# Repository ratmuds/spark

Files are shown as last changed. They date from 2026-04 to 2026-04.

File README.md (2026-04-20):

# spark

an electronic multitool in the shape of a card

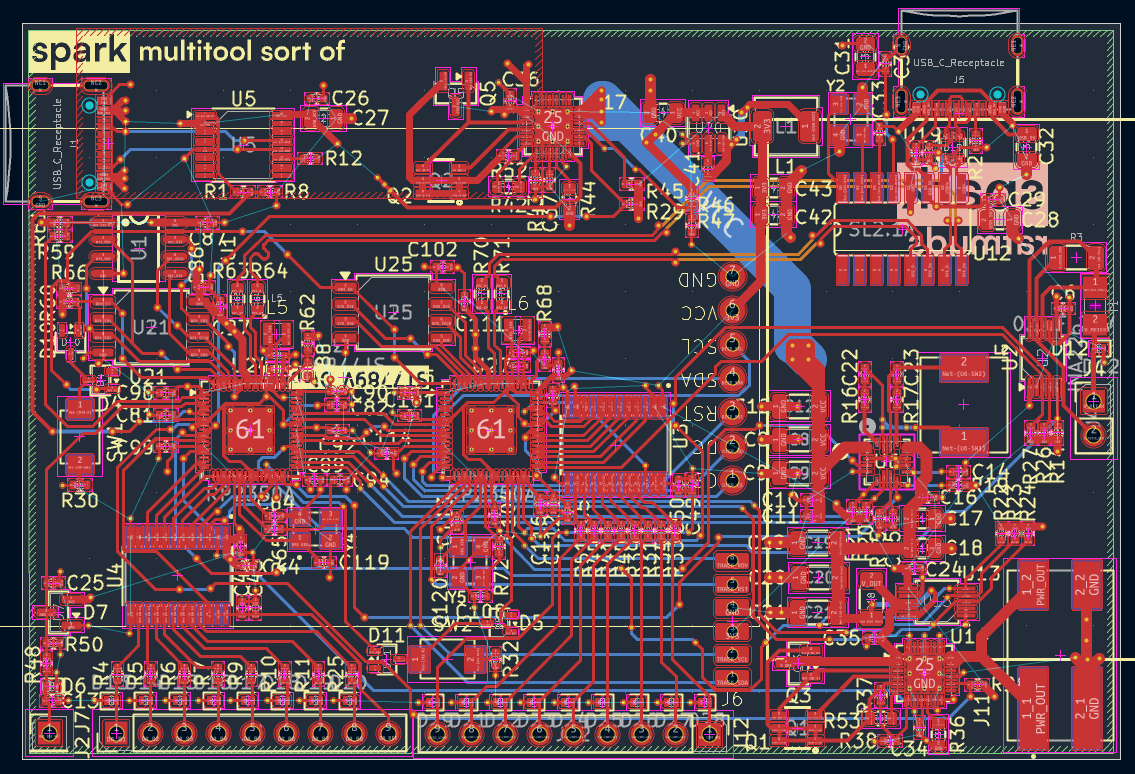
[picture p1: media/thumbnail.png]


# Features

- dual RP2350As (one logic analyzer & power, other LVGL & inputs)
- 8 channel logic analyzer
- very slow ADC
- GPIO
- up to 20V 3A power output

# Files

- `/case`: The CAD for the case for the PCB. Includes a Fusion archive file, step, and stl file
- `/firmware`: Includes the firmware for both MCUs for this project. `/main` is in Rust and handles the logic analyzer, and `/secondary` is the input and LVGL C files
- `/PCB`: The PCB files for this project. The producton/gerber files are in `/production`
- `/media`: The screenshots/renders

## More Screenshots

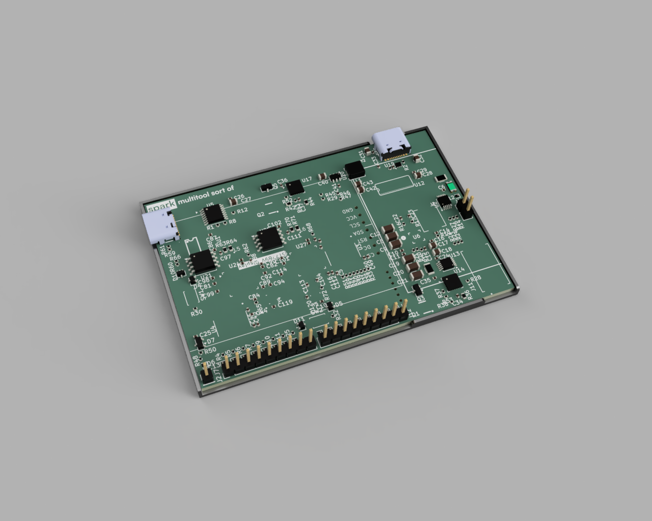
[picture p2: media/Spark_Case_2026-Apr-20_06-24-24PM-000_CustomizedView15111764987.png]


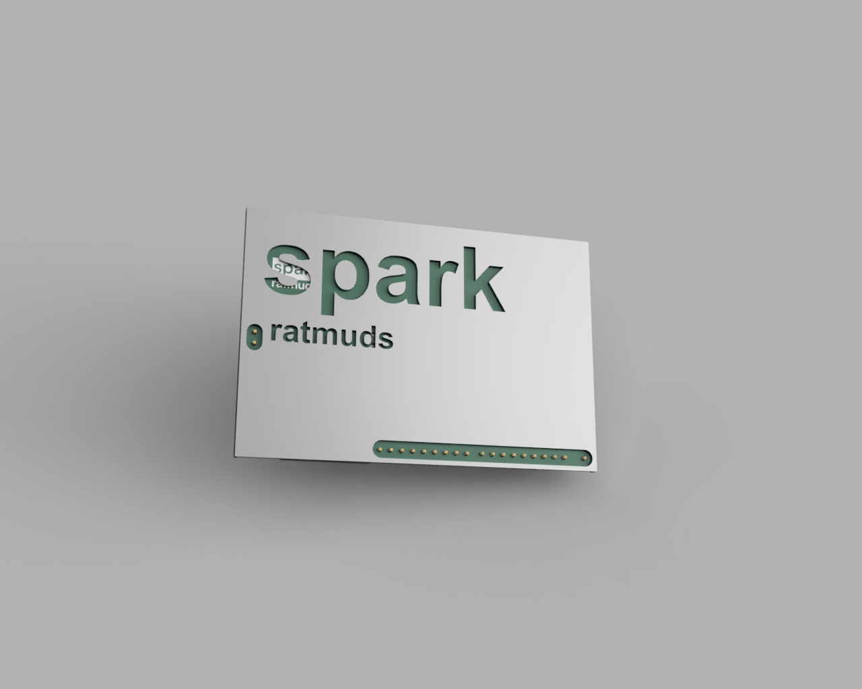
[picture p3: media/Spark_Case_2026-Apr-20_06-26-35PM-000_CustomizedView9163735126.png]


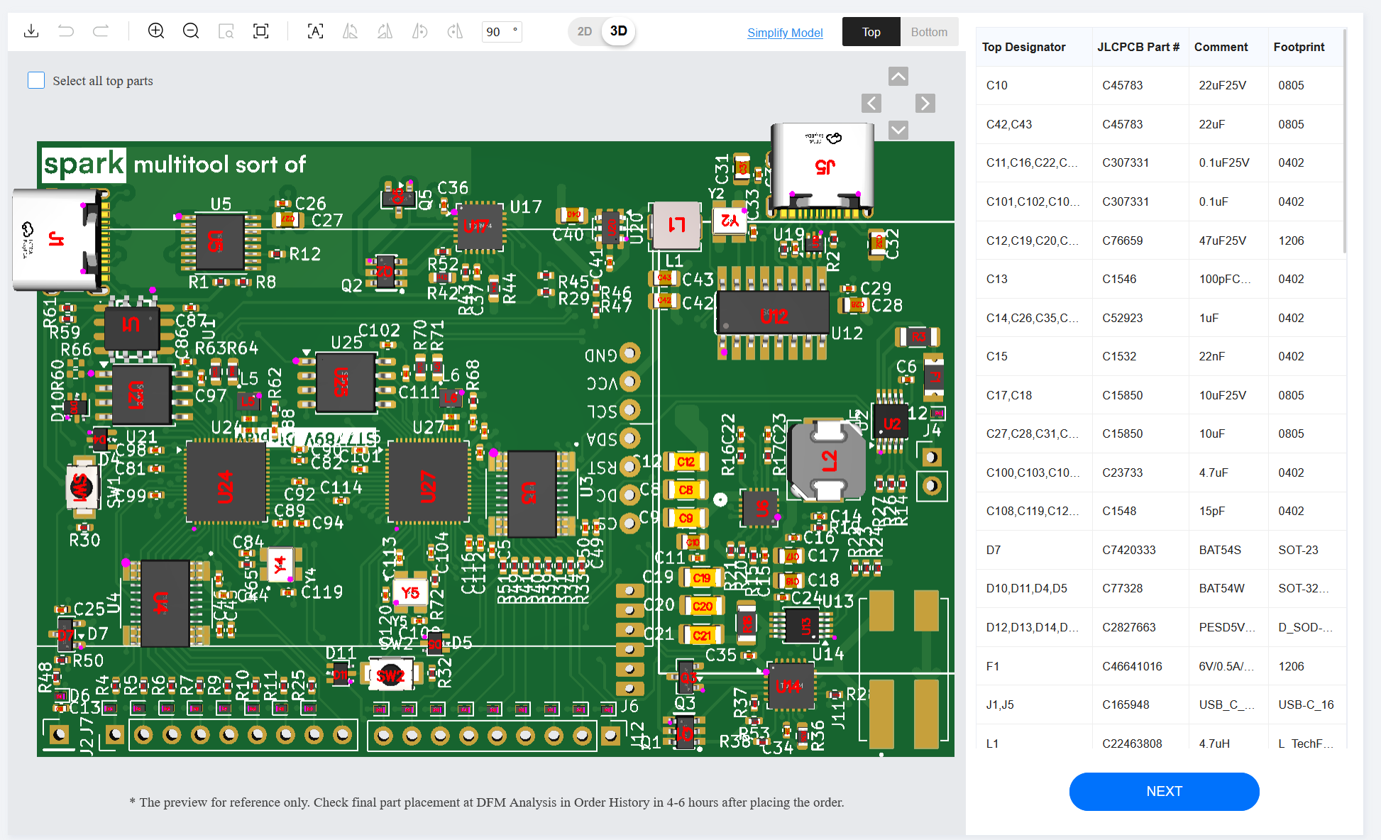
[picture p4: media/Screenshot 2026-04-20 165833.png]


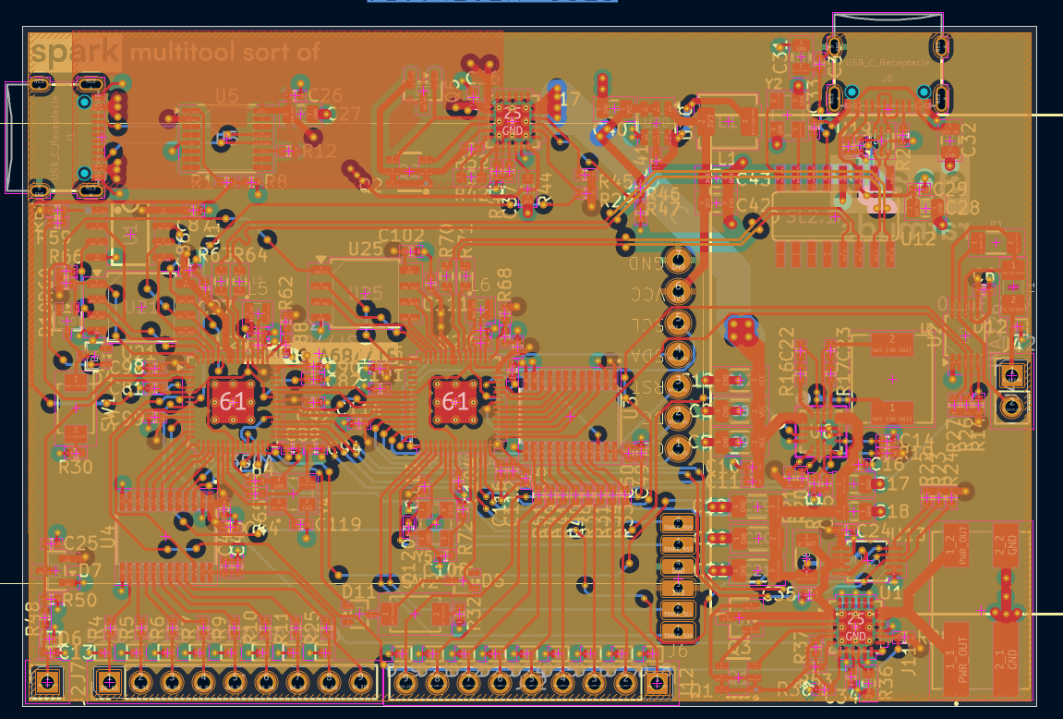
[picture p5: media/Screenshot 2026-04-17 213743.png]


## Bill of Materials

You can also view the BOM in `BOM.csv`

| Name | Description | Link |
| --- | --- | --- |
| RP2350A | Dual-core ARM Cortex-M33 / RISC-V microcontroller 30 GPIO QFN-60 (x2) | https://jlcpcb.com/partdetail/RaspberryPi-RP2350A/C42411118 |
| W25Q128JVSIQ | 128Mbit SPI NOR Flash SOIC-8 (x2) | https://jlcpcb.com/partdetail/WinbondElec-W25Q128JVSIQ/C97521 |
| APS6404L-SQN-SN | 64Mbit QSPI PSRAM SOP-8 (x1) | https://jlcpcb.com/partdetail/APMemory-APS6404L_SQNSN/C5360304 |
| INA226AIDGSR | 36V 16-bit I2C Power Monitor TSSOP-10 (x2) | https://jlcpcb.com/partdetail/TexasInstruments-INA226AIDGSR/C49851 |
| SN74LVC8T245PWR | 8-bit dual-supply level shifter TSSOP-24 (x2) | https://jlcpcb.com/partdetail/TexasInstruments-SN74LVC8T245PWR/C27643 |
| IP2721 | USB PD sink controller TSSOP-16 (x1) | https://jlcpcb.com/partdetail/INJOINIC-IP2721/C603176 |
| MP8859GQ-0000-Z | Programmable synchronous buck converter QFN-16 (x1) | https://jlcpcb.com/partdetail/MPS-MP8859GQ_0000Z/C5439043 |
| SL2.1A | 4-port USB 2.0 hub controller SO-16 (x1) | https://jlcpcb.com/partdetail/Corechips-SL21A/C192893 |
| TPS26630RGER | 45V 5.5A eFuse with reverse polarity VQFN-24 (x2) | https://jlcpcb.com/partdetail/TexasInstruments-TPS26630RGER/C1850276 |
| USBLC6-2P6 | USB ESD protection SOT-666 (x1) | https://jlcpcb.com/partdetail/STMicroelectronics-USBLC62P6/C15999 |
| AP63203WU-7 | 3.3V 2A synchronous buck converter TSOT-23-6 (x1) | https://jlcpcb.com/partdetail/DiodesIncorporated-AP63203WU7/C780769 |
| ABM8-272-T3 | 12MHz crystal oscillator RPi recommended SMD (x3) | https://jlcpcb.com/partdetail/AbraconLlc-ABM8_272T3/C20625731 |
| AOTA-B201610S3R3-101-T | 3.3uH polarised inductor for RP2350 DVDD SMPS 2016 (x2) | https://jlcpcb.com/partdetail/AbraconLlc-AOTA_B201610S3R3_101T/C42411119 |
| SRP4020TA-4R7M | 4.7uH 2.6A shielded power inductor for MP8859 (x1) | https://jlcpcb.com/partdetail/BOURNS-SRP4020TA4R7M/C2041623 |
| SPM6530T-4R7M | 4.7uH TDK power inductor for USB PD path (x1) | https://jlcpcb.com/parts/componentSearch?searchTxt=SPM6530T-4R7M |
| STT6N3LLH6 | N-channel 30V 6A MOSFET SOT-23-6 (x2) | https://jlcpcb.com/partdetail/C3021100 |
| BSS138 | N-channel 50V 0.2A logic-level MOSFET SOT-23 (x2) | https://jlcpcb.com/partdetail/Onsemi-BSS138/C52895 |
| BAT54W | 30V 200mA dual Schottky diode SOT-323 (x4) | https://jlcpcb.com/partdetail/ZRE-BAT54W/C779673 |
| BAT54S | 30V 200mA dual Schottky diode SOT-23 (x1) | https://jlcpcb.com/partdetail/hongjiacheng-BAT54S/C7420333 |
| PESD5V0U1BL | 5V ESD protection diode SOD-882 (x19) | https://jlcpcb.com/partdetail/TECHPUBLIC-PESD5V0U1BL/C2827663 |
| 1206L050YR | 6V 0.5A/1A resettable fuse 1206 (x1) | https://jlcpcb.com/parts/componentSearch?searchTxt=1206L050YR |
| TYPE-C-31-M-12 | USB Type-C receptacle SMD 16-pin (x2) | https://jlcpcb.com/partdetail/Korean_HropartsElec-TYPE_C_31_M12/C165948  |
| RLS12FTCR020 | 20mΩ 1W current sense resistor 1206 (x2) | https://jlcpcb.com/parts/componentSearch?searchTxt=RLS12FTCR020 |
| 0402WGF1003TCE | 100kΩ 1% 0402 resistor (x5) | https://jlcpcb.com/partdetail/UniOhm-0402WGF1003TCE/C25803 |
| 0402WGF5101TCE | 5.1kΩ 1% 0402 resistor for USB CC (x2) | https://jlcpcb.com/partdetail/UniOhm-0402WGF5101TCE/C27091 |
| 0402WGF470JTCE | 47Ω 5% 0402 resistor (x16) | https://jlcpcb.com/partdetail/UniOhm-0402WGF470JTCE/C25900 |
| 0402WGF1502TCE | 15kΩ 1% 0402 resistor (x1) | https://jlcpcb.com/partdetail/UniOhm-0402WGF1502TCE/C25749 |
| 0402WGF4701TCE | 4.7kΩ 1% 0402 resistor (x6) | https://jlcpcb.com/partdetail/UniOhm-0402WGF4701TCE/C25905 |
| 0402WGF2202TCE | 22kΩ 1% 0402 resistor (x1) | https://jlcpcb.com/partdetail/UniOhm-0402WGF2202TCE/C25888 |
| 0402WGF0000TCE | 0Ω 0402 jumper resistor (x3) | https://jlcpcb.com/partdetail/UniOhm-0402WGF0000TCE/C17168 |
| 0402WGF1002TCE | 10kΩ 1% 0402 resistor (x7) | https://jlcpcb.com/partdetail/UniOhm-0402WGF1002TCE/C25744 |
| 0402WGF1001TCE | 1kΩ 1% 0402 resistor (x4) | https://jlcpcb.com/partdetail/UniOhm-0402WGF1001TCE/C21190 |
| 0603WAF6201T5E | 6.2kΩ 1% 0603 resistor ILIM for TPS26630 (x1) | https://jlcpcb.com/parts/componentSearch?searchTxt=0603WAF6201T5E |
| 0402WGF4703TCE | 470kΩ 1% 0402 resistor UVLO divider (x1) | https://jlcpcb.com/partdetail/26533-0402WGF4703TCE/C25790 |
| 0402WGF2402TCE | 24kΩ 1% 0402 resistor UVLO divider (x3) | https://jlcpcb.com/partdetail/UniOhm-0402WGF2402TCE/C25769 |
| 0603WAF1603T5E | 160kΩ 1% 0603 resistor UVLO network (x1) | https://jlcpcb.com/partdetail/UniOhm-0603WAF1603T5E/C22813 |
| FRC0603F3571TS | 3.57kΩ 1% 0603 resistor ILIM for TPS26630 (x1) | https://jlcpcb.com/partdetail/C2933206 |
| 0402WGF1503TCE | 150kΩ 1% 0402 resistor PGTH divider (x1) | https://jlcpcb.com/partdetail/UniOhm-0402WGF1503TCE/C25755 |
| 0402WGF8201TCE | 8.2kΩ 1% 0402 resistor ADC input protection (x1) | https://jlcpcb.com/partdetail/UniOhm-0402WGF8201TCE/C25924 |
| 0402WGF3303TCE | 330kΩ 1% 0402 resistor UVLO network (x1) | https://jlcpcb.com/partdetail/UniOhm-0402WGF3303TCE/C25778 |
| 0402WGF3003TCE | 300kΩ 1% 0402 resistor OVP divider (x1) | https://jlcpcb.com/partdetail/UniOhm-0402WGF3003TCE/C25774 |
| 0402WGF330JTCE | 33Ω 5% 0402 resistor USB D+/D- (x2) | https://jlcpcb.com/partdetail/UniOhm-0402WGF330JTCE/C25105 |
| 0603WAF270JT5E | 27Ω 5% 0603 resistor USB D+/D- (x4) | https://jlcpcb.com/partdetail/UniOhm-0603WAF270JT5E/C25190 |
| CL05B104KB54PNC | 100nF 50V X7R 0402 decoupling capacitor (x38) | https://jlcpcb.com/parts/componentSearch?searchTxt=CL05B104KB54PNC |
| CL05A105KA5NQNC | 1uF 25V X5R 0402 capacitor (x7) | https://jlcpcb.com/parts/componentSearch?searchTxt=CL05A105KA5NQNC |
| C3216X5R1E476MTJ00E | 47uF 25V X5R 1206 bulk capacitor (x6) | https://jlcpcb.com/parts/componentSearch?searchTxt=C3216X5R1E476MTJ00E |
| CGA2B2X7R1E223KT0Y0F | 22uF 25V X7R 0402 capacitor (x1) | https://jlcpcb.com/parts/componentSearch?searchTxt=CGA2B2X7R1E223KT0Y0F  |
| 0402CG101J500NT | 100pF C0G/NP0 0402 capacitor (x1) | https://jlcpcb.com/parts/componentSearch?searchTxt=0402CG101J500NT |
| 0402B223K500NT | 22nF 50V 0402 capacitor (x1) | https://jlcpcb.com/parts/componentSearch?searchTxt=0402B223K500NT |
| CL21A106KAYNNNE | 10uF 25V X5R 0805 capacitor (x7) | https://jlcpcb.com/parts/componentSearch?searchTxt=CL21A106KAYNNNE |
| CL21A226MAQNNNE | 22uF 25V X5R 0805 capacitor (x2) | https://jlcpcb.com/parts/componentSearch?searchTxt=CL21A226MAQNNNE |
| CL05A475MP5NRNC | 4.7uF 10V X5R 0402 capacitor (x8) | https://jlcpcb.com/parts/componentSearch?searchTxt=CL05A475MP5NRNC |
| 0402CG150J500NT | 15pF 50V C0G/NP0 0402 crystal load capacitor (x4) | https://jlcpcb.com/parts/componentSearch?searchTxt=0402CG150J500NT |

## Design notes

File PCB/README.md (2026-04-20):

# PCB

The PCB files for this project. The gerber and other PCBA files are in the `production` folder.

This PCB was made using **KiCad 10**, and took around **40 hours** to make.

## PCB Design Screenshots

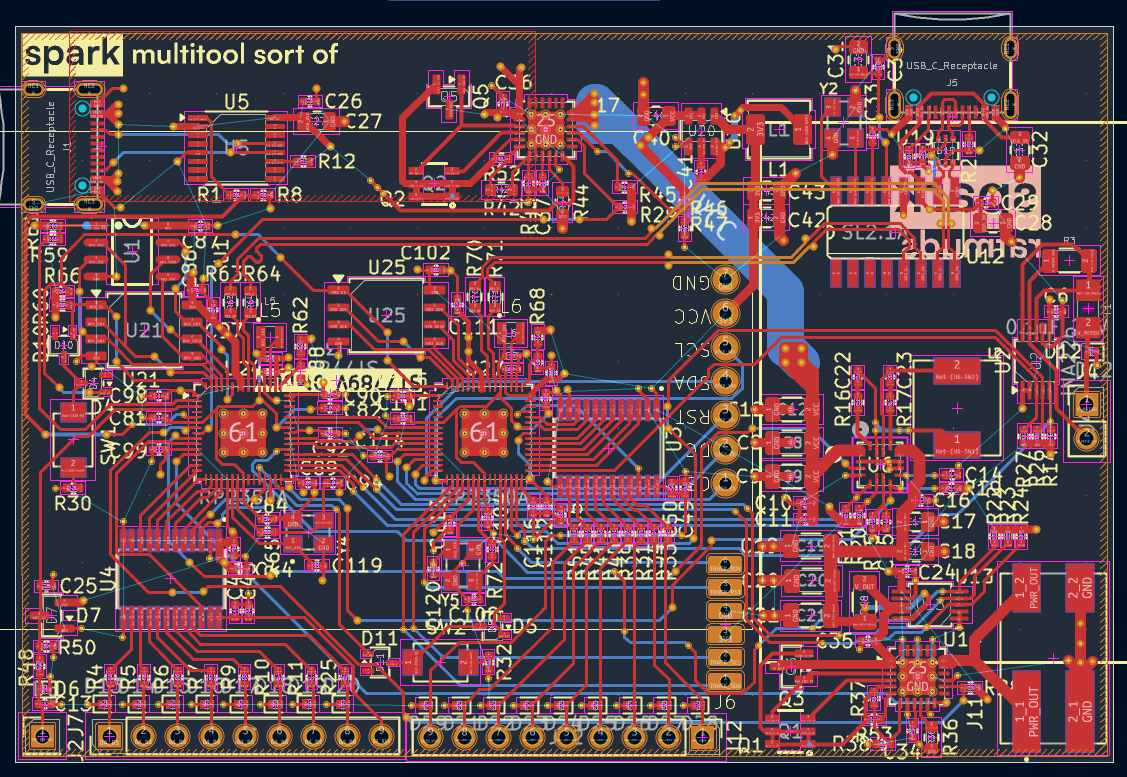
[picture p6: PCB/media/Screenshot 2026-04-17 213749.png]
 

## Schematic Screenshots

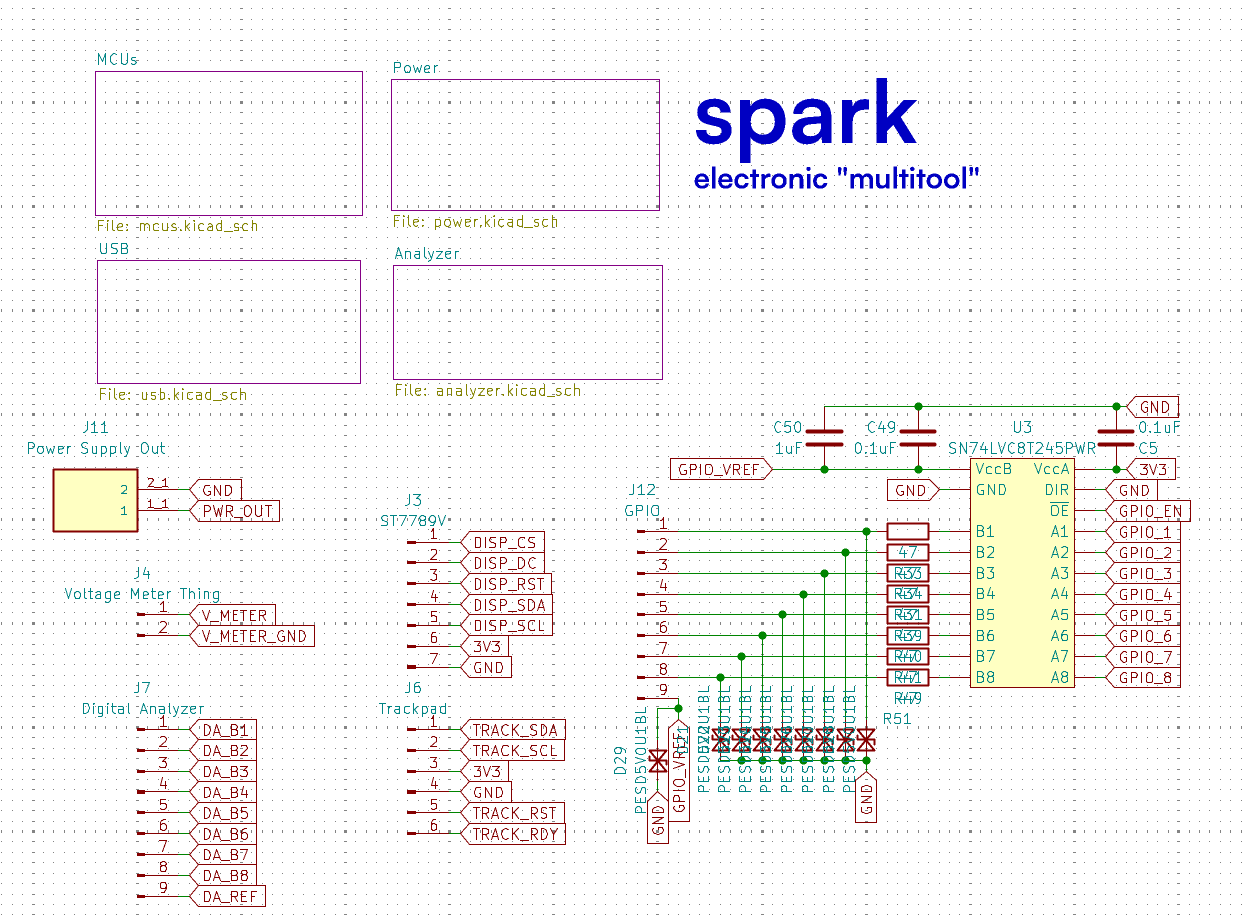
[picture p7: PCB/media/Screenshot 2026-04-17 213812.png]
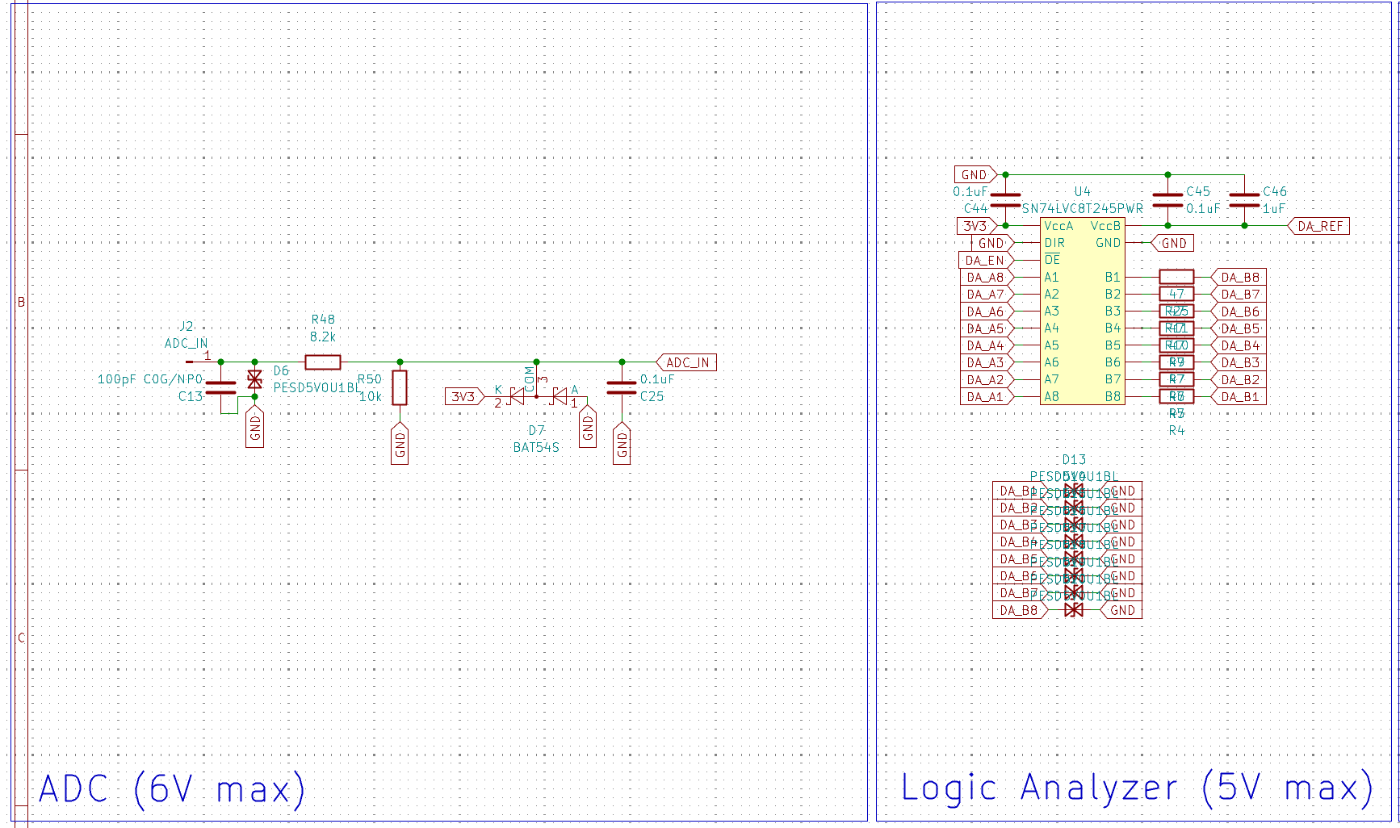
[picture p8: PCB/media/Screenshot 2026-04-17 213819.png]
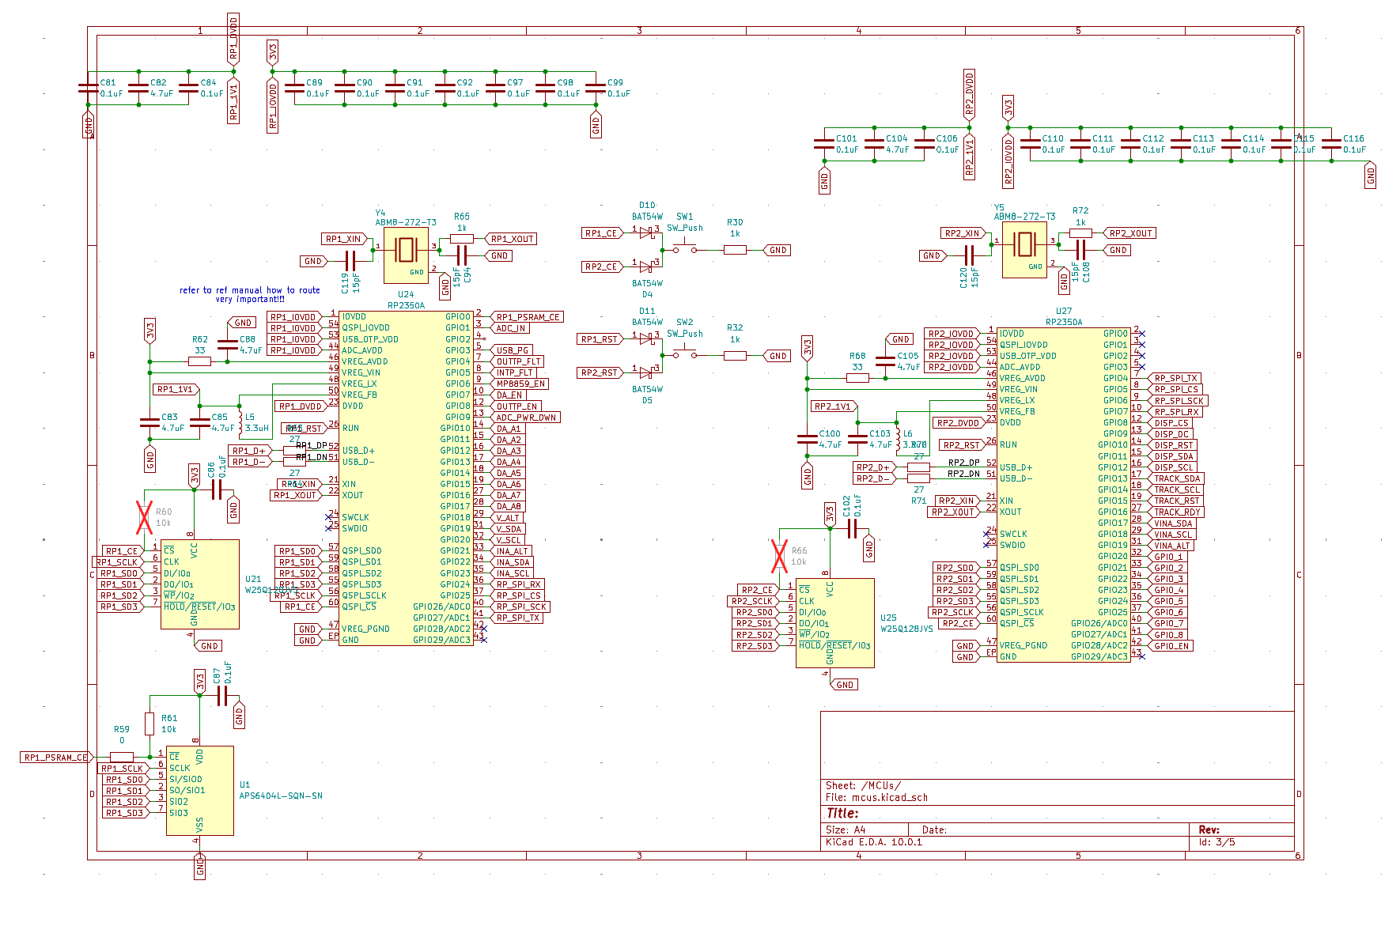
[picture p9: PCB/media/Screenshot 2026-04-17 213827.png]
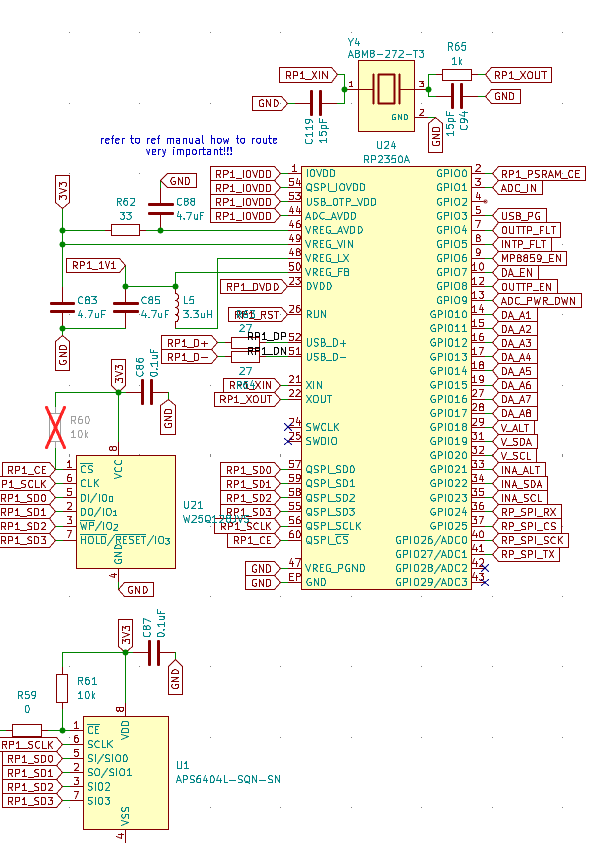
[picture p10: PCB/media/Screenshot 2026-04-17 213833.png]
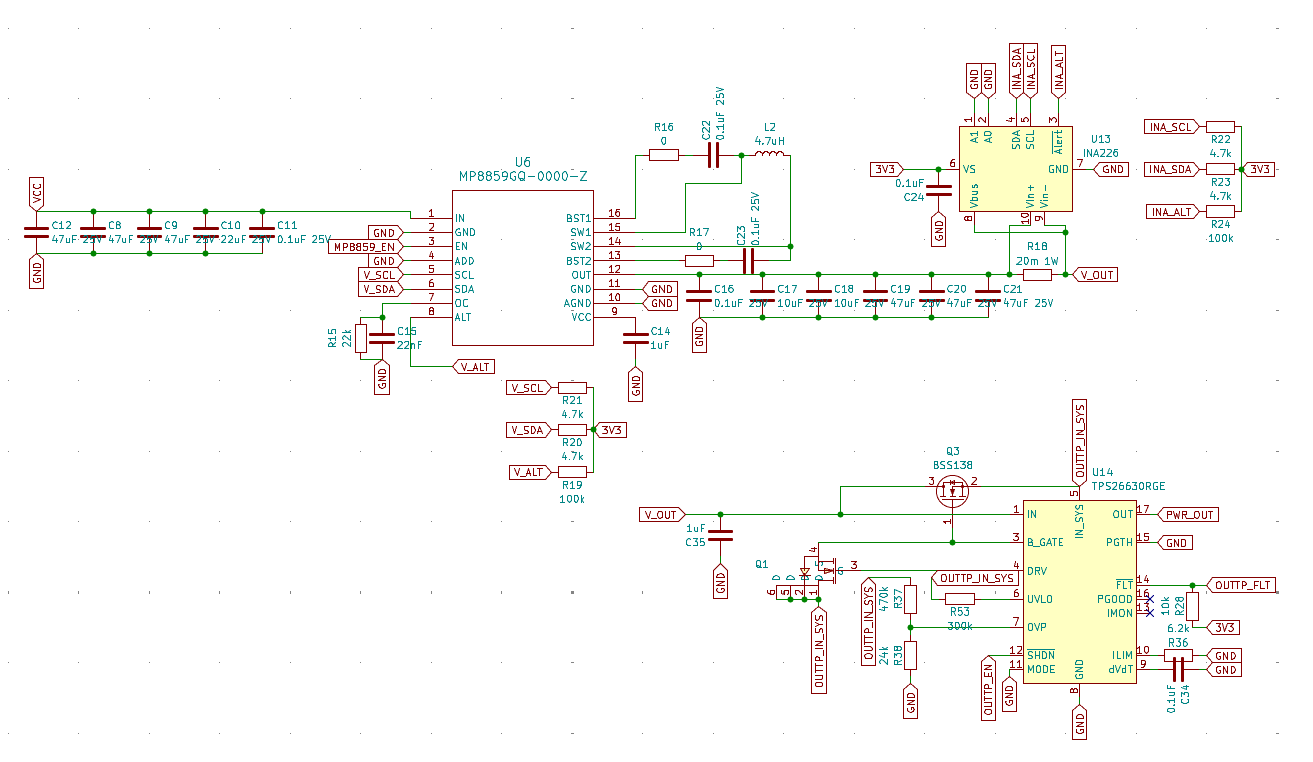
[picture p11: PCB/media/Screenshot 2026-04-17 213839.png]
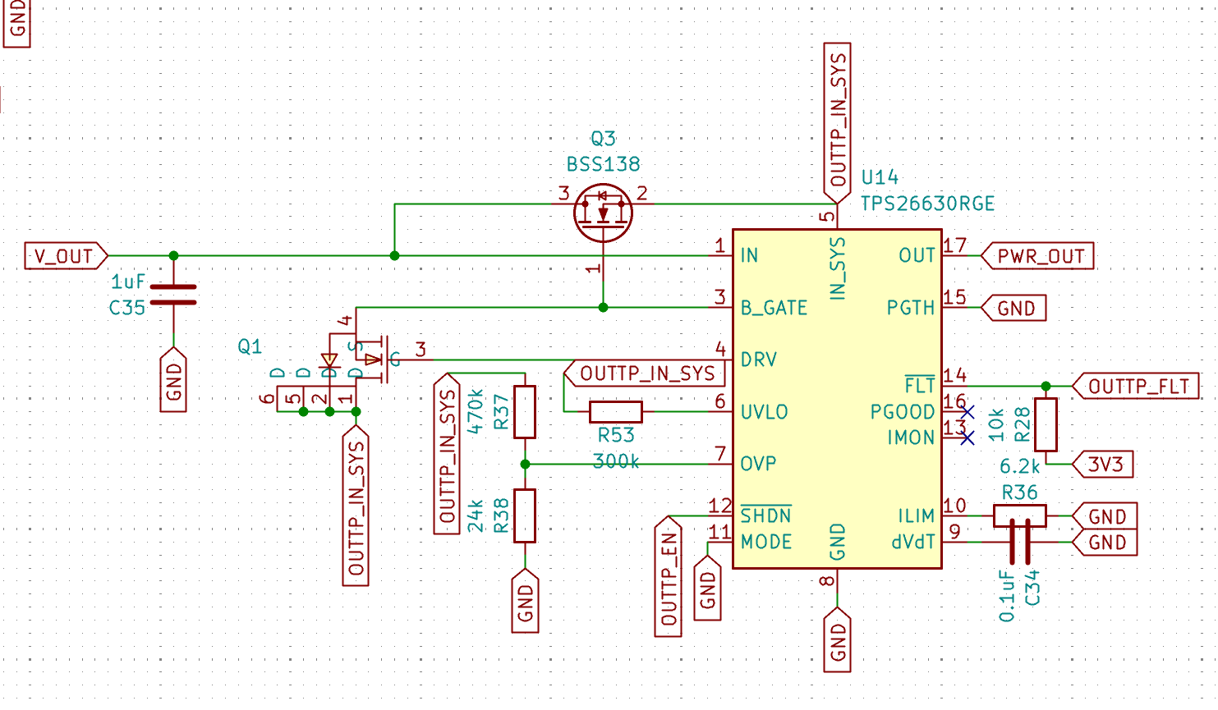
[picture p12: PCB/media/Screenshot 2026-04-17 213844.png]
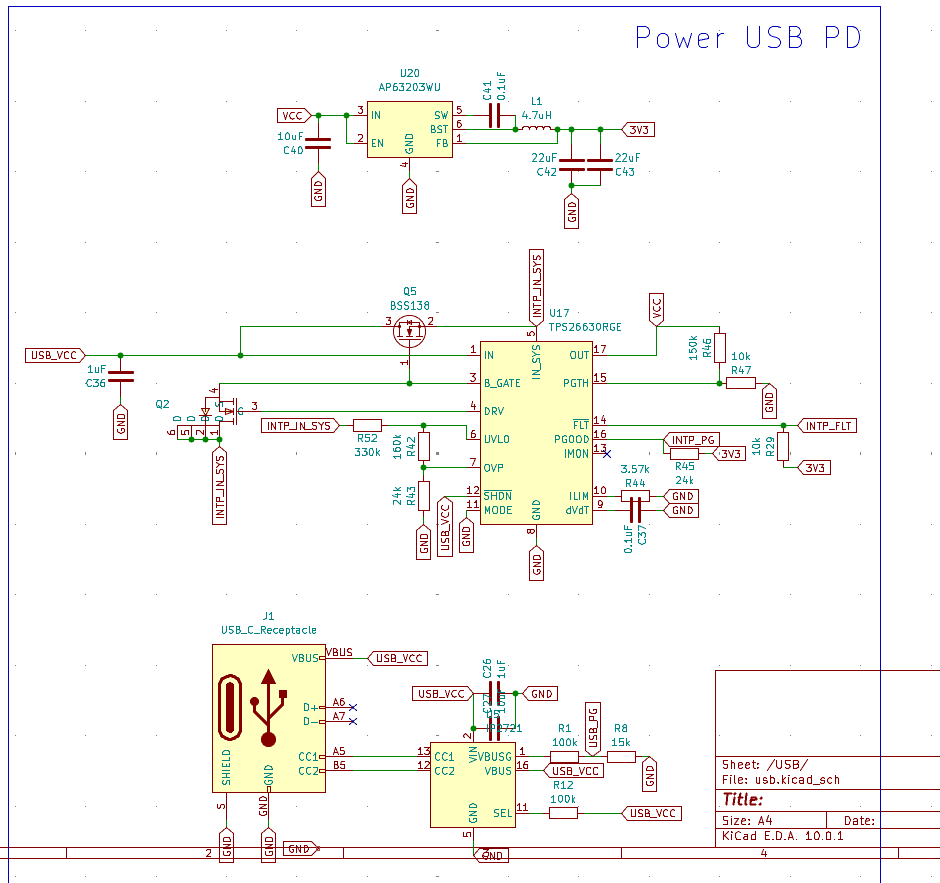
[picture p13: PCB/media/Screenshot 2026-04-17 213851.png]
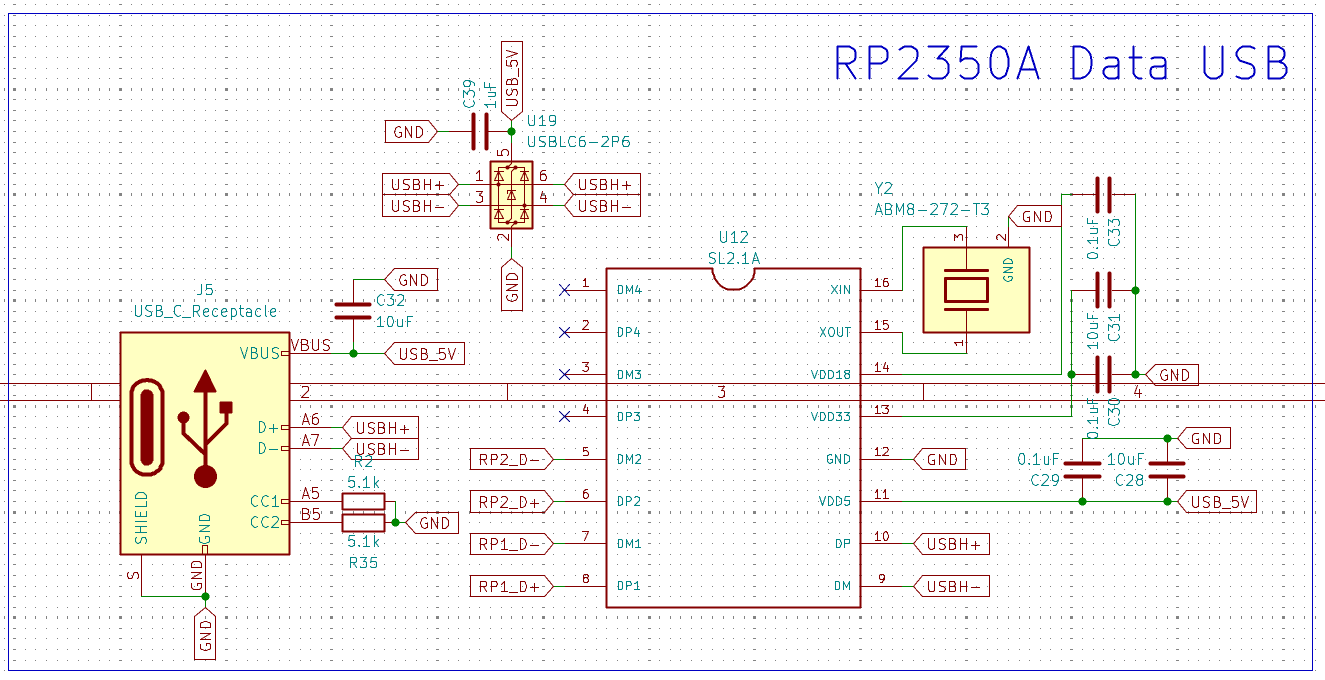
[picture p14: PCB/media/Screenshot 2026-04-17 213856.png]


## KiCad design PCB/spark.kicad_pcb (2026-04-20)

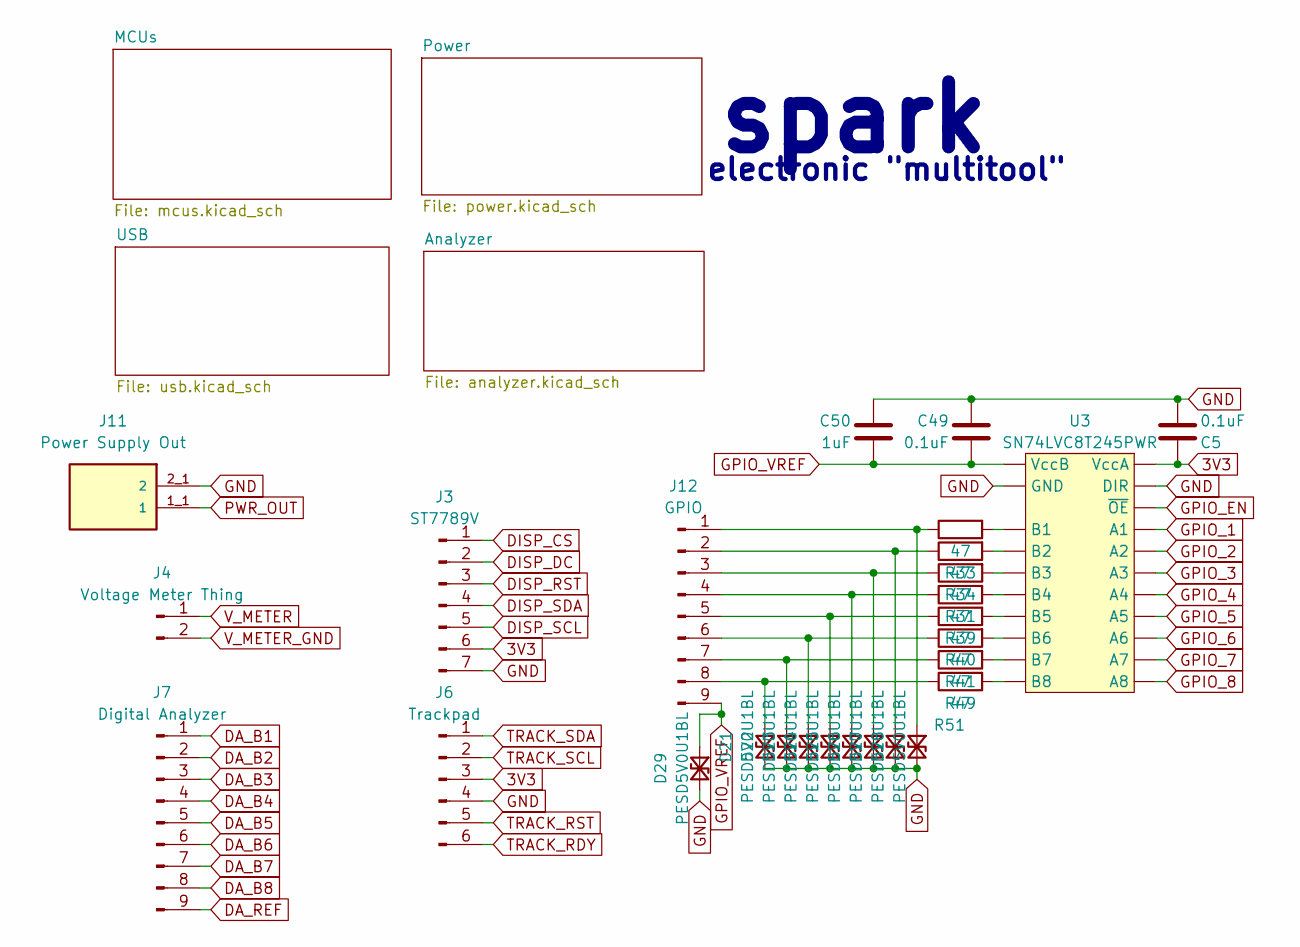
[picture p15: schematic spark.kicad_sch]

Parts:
C5, C49: 0.1uF; C_0402_1005Metric; MPN CL05B104KB54PNC
C50: 1uF; C_0402_1005Metric; MPN CL05A105KA5NQNC
D21, D22, D23, D24, D25, D26, D27, D28, D29: PESD5V0U1BL; D_SOD-882; MPN PESD5V0U1BL
J3: ST7789V; ST7789V Display Breakout
J4: Voltage Meter Thing; PinHeader_1x02_P2.54mm_Vertical
J6: Trackpad; SMD_Conn_01x07
J7: Digital Analyzer; PinHeader_1x09_P2.54mm_Vertical
J11: Power Supply Out; WAGO_2060-452_998-404; PARTREV N/A
J12: GPIO; PinHeader_1x09_P2.54mm_Vertical
R31, R33, R34, R39, R40, R41, R49, R51: 47; R_0402_1005Metric; MPN 0402WGF470JTCE
U3: SN74LVC8T245PWR; SOP65P640X120-24N; MPN SN74LVC8T245PWR; LCSC C27643

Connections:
3V3: C5.2, J3.6, J6.3, U3.1 (VccA); also elsewhere on the board
DA_B1: J7.1; also elsewhere on the board
DA_B2: J7.2; also elsewhere on the board
DA_B3: J7.3; also elsewhere on the board
DA_B4: J7.4; also elsewhere on the board
DA_B5: J7.5; also elsewhere on the board
DA_B6: J7.6; also elsewhere on the board
DA_B7: J7.7; also elsewhere on the board
DA_B8: J7.8; also elsewhere on the board
DA_REF: J7.9; also elsewhere on the board
DISP_CS: J3.1; also elsewhere on the board
DISP_DC: J3.2; also elsewhere on the board
DISP_RST: J3.3; also elsewhere on the board
DISP_SCL: J3.5; also elsewhere on the board
DISP_SDA: J3.4; also elsewhere on the board
GND: C5.1, C49.2, C50.2, D21.2 (A2), D22.2 (A2), D23.2 (A2), D24.2 (A2), D25.2 (A2), D26.2 (A2), D27.2 (A2), D28.2 (A2), D29.2 (A2), J3.7, J6.4, J11.2_1 (2), J11.2_2 (2), U3.2 (DIR), U3.11 (GND), U3.12 (GND), U3.13 (GND); also elsewhere on the board
GPIO_1: U3.3 (A1); also elsewhere on the board
GPIO_2: U3.4 (A2); also elsewhere on the board
GPIO_3: U3.5 (A3); also elsewhere on the board
GPIO_4: U3.6 (A4); also elsewhere on the board
GPIO_5: U3.7 (A5); also elsewhere on the board
GPIO_6: U3.8 (A6); also elsewhere on the board
GPIO_7: U3.9 (A7); also elsewhere on the board
GPIO_8: U3.10 (A8); also elsewhere on the board
GPIO_EN: U3.22 (~OE); also elsewhere on the board
GPIO_VREF: C49.1, C50.1, D29.1 (A1), J12.9, U3.23 (VccB), U3.24 (VccB)
unnamed: D21.1 (A1), J12.8, R51.1
unnamed: D22.1 (A1), J12.7, R49.1
unnamed: D23.1 (A1), J12.6, R41.1
unnamed: D24.1 (A1), J12.5, R40.1
unnamed: D25.1 (A1), J12.4, R39.1
unnamed: D26.1 (A1), J12.3, R31.1
unnamed: D27.1 (A1), J12.2, R34.1
unnamed: D28.1 (A1), J12.1, R33.1
unnamed: R33.2, U3.21 (B1)
unnamed: R34.2, U3.20 (B2)
unnamed: R31.2, U3.19 (B3)
unnamed: R39.2, U3.18 (B4)
unnamed: R40.2, U3.17 (B5)
unnamed: R41.2, U3.16 (B6)
unnamed: R49.2, U3.15 (B7)
unnamed: R51.2, U3.14 (B8)
PWR_OUT: J11.1_1 (1), J11.1_2 (1); also elsewhere on the board
TRACK_RDY: J6.6; also elsewhere on the board
TRACK_RST: J6.5; also elsewhere on the board
TRACK_SCL: J6.2; also elsewhere on the board
TRACK_SDA: J6.1; also elsewhere on the board
V_METER: J4.1; also elsewhere on the board
V_METER_GND: J4.2; also elsewhere on the board

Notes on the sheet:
spark
electronic "multitool"

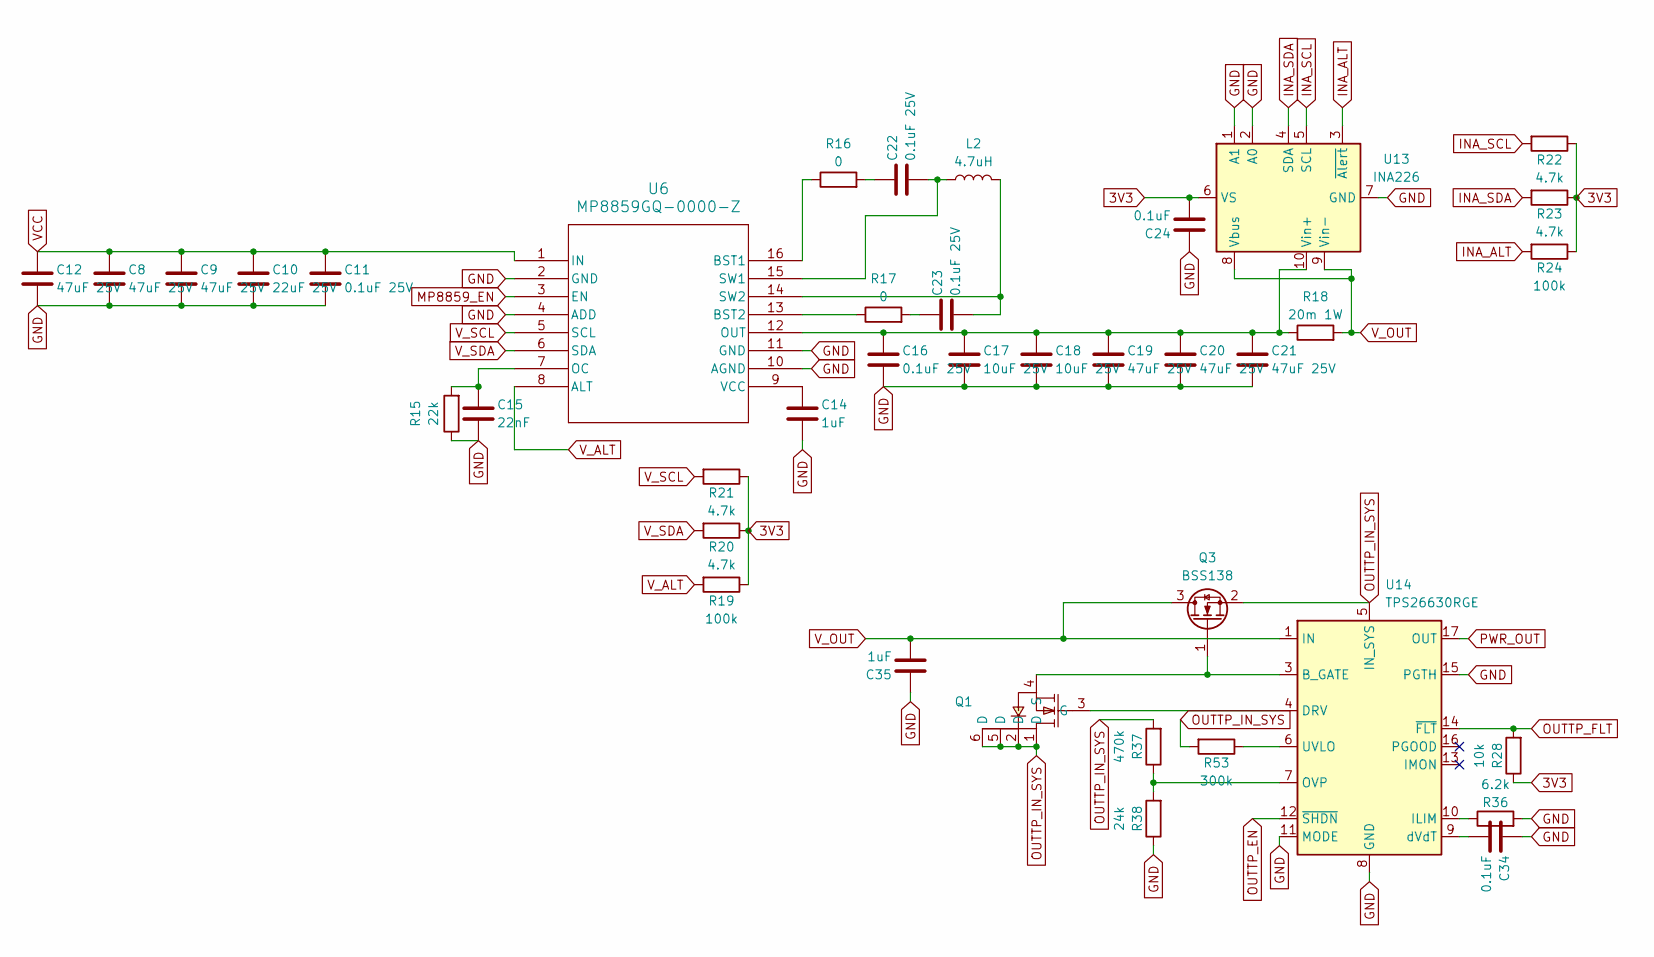
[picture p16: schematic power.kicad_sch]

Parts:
C8, C9, C12, C19, C20, C21: 47uF 25V; C_1206_3216Metric; MPN C3216X5R1E476MTJ00E
C10: 22uF 25V; C_0805_2012Metric; MPN CL21A226MAQNNNE
C11, C16, C22, C23: 0.1uF 25V; C_0402_1005Metric; MPN CL05B104KB54PNC
C14, C35: 1uF; C_0402_1005Metric; MPN CL05A105KA5NQNC
C15: 22nF; C_0402_1005Metric; MPN 0402B223K500NT
C17, C18: 10uF 25V; C_0805_2012Metric; MPN CL21A106KAYNNNE
C24, C34: 0.1uF; C_0402_1005Metric; MPN CL05B104KB54PNC
L2: 4.7uH; IND_SPM6530T-4R7M; MPN SPM6530T-4R7M
Q1: STT6N3LLH6_C3021100; SOT-23-6_L2.9-W1.6-P0.95-LS2.8-BR; MPN STT6N3LLH6; LCSC Part C3021100
Q3: BSS138; SOT-23; MPN BSS138
R15: 22k; R_0402_1005Metric; MPN 0402WGF2202TCE
R16, R17: 0; R_0402_1005Metric; MPN 0402WGF0000TCE
R18: 20m 1W; R_1206_3216Metric; MPN RLS12FTCR020
R19, R24: 100k; R_0402_1005Metric; MPN 0402WGF1003TCE
R20, R21, R22, R23: 4.7k; R_0402_1005Metric; MPN 0402WGF4701TCE
R28: 10k; R_0402_1005Metric; MPN 0402WGF1002TCE
R36: 6.2k; R_0603_1608Metric; MPN 0603WAF6201T5E
R37: 470k; R_0402_1005Metric; MPN 0402WGF4703TCE
R38: 24k; R_0402_1005Metric; MPN 0402WGF2402TCE
R53: 300k; R_0402_1005Metric; MPN 0402WGF3003TCE
U6: MP8859GQ-0000-Z; QFN-16_MP8859_00_MNP; MPN MP8859GQ-0000-Z
U13: INA226; TSSOP-10_3x3mm_P0.5mm; MPN INA226AIDGSR
U14: TPS26630RGE; Texas_RGE0024H_VQFN-24-1EP_4x4mm_P0.5mm_EP2.7x2.7mm_Thermal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; MPN TPS26630RGER

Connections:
3V3: C24.1, R19.1, R20.1, R21.1, R22.1, R23.1, R24.1, R28.1, U13.6 (VS); also elsewhere on the board
GND: C8.1, C9.1, C10.1, C11.1, C12.1, C14.1, C15.1, C16.1, C17.1, C18.1, C19.1, C20.1, C21.1, C24.2, C34.2, C35.2, R15.1, R36.2, R38.1, U6.2 (GND), U6.4 (ADD), U6.10 (AGND), U6.11 (GND), U13.1 (A1), U13.2 (A0), U13.7 (GND), U14.8 (GND), U14.11 (MODE), U14.15 (PGTH), U14.25 (GND); also elsewhere on the board
INA_ALT: R24.2, U13.3 (~Alert); also elsewhere on the board
INA_SCL: R22.2, U13.5 (SCL); also elsewhere on the board
INA_SDA: R23.2, U13.4 (SDA); also elsewhere on the board
MP8859_EN: U6.3 (EN); also elsewhere on the board
unnamed: C22.2, R16.2
unnamed: C23.2, R17.2
unnamed: Q1.3 (G), U14.4 (DRV)
unnamed: Q1.4 (S), Q3.1 (G), U14.3 (B_GATE)
unnamed: R16.1, U6.16 (BST1)
unnamed: R17.1, U6.13 (BST2)
unnamed: C15.2, R15.2, U6.7 (OC)
unnamed: C22.1, L2.1, U6.15 (SW1)
unnamed: C23.1, L2.2, U6.14 (SW2)
unnamed: C14.2, U6.9 (VCC)
unnamed: C16.2, C17.2, C18.2, C19.2, C20.2, C21.2, R18.1, U6.12 (OUT), U13.10 (Vin+)
unnamed: R36.1, U14.10 (ILIM)
unnamed: R37.1, R38.2, U14.7 (OVP)
unnamed: R53.1, U14.6 (UVLO)
unnamed: C34.1, U14.9 (dVdT)
OUTTP_EN: U14.12 (~SHDN); also elsewhere on the board
OUTTP_FLT: R28.2, U14.14 (~FLT); also elsewhere on the board
OUTTP_IN_SYS: Q1.1 (D), Q1.2 (D), Q1.5 (D), Q1.6 (D), Q3.2 (S), R37.2, R53.2, U14.5 (IN_SYS)
PWR_OUT: U14.17 (OUT), U14.18 (OUT); also elsewhere on the board
VCC: C8.2, C9.2, C10.2, C11.2, C12.2, U6.1 (IN); also elsewhere on the board
V_ALT: R19.2, U6.8 (ALT); also elsewhere on the board
V_OUT: C35.1, Q3.3 (D), R18.2, U13.8 (Vbus), U13.9 (Vin-), U14.1 (IN), U14.2 (IN)
V_SCL: R21.2, U6.5 (SCL); also elsewhere on the board
V_SDA: R20.2, U6.6 (SDA); also elsewhere on the board

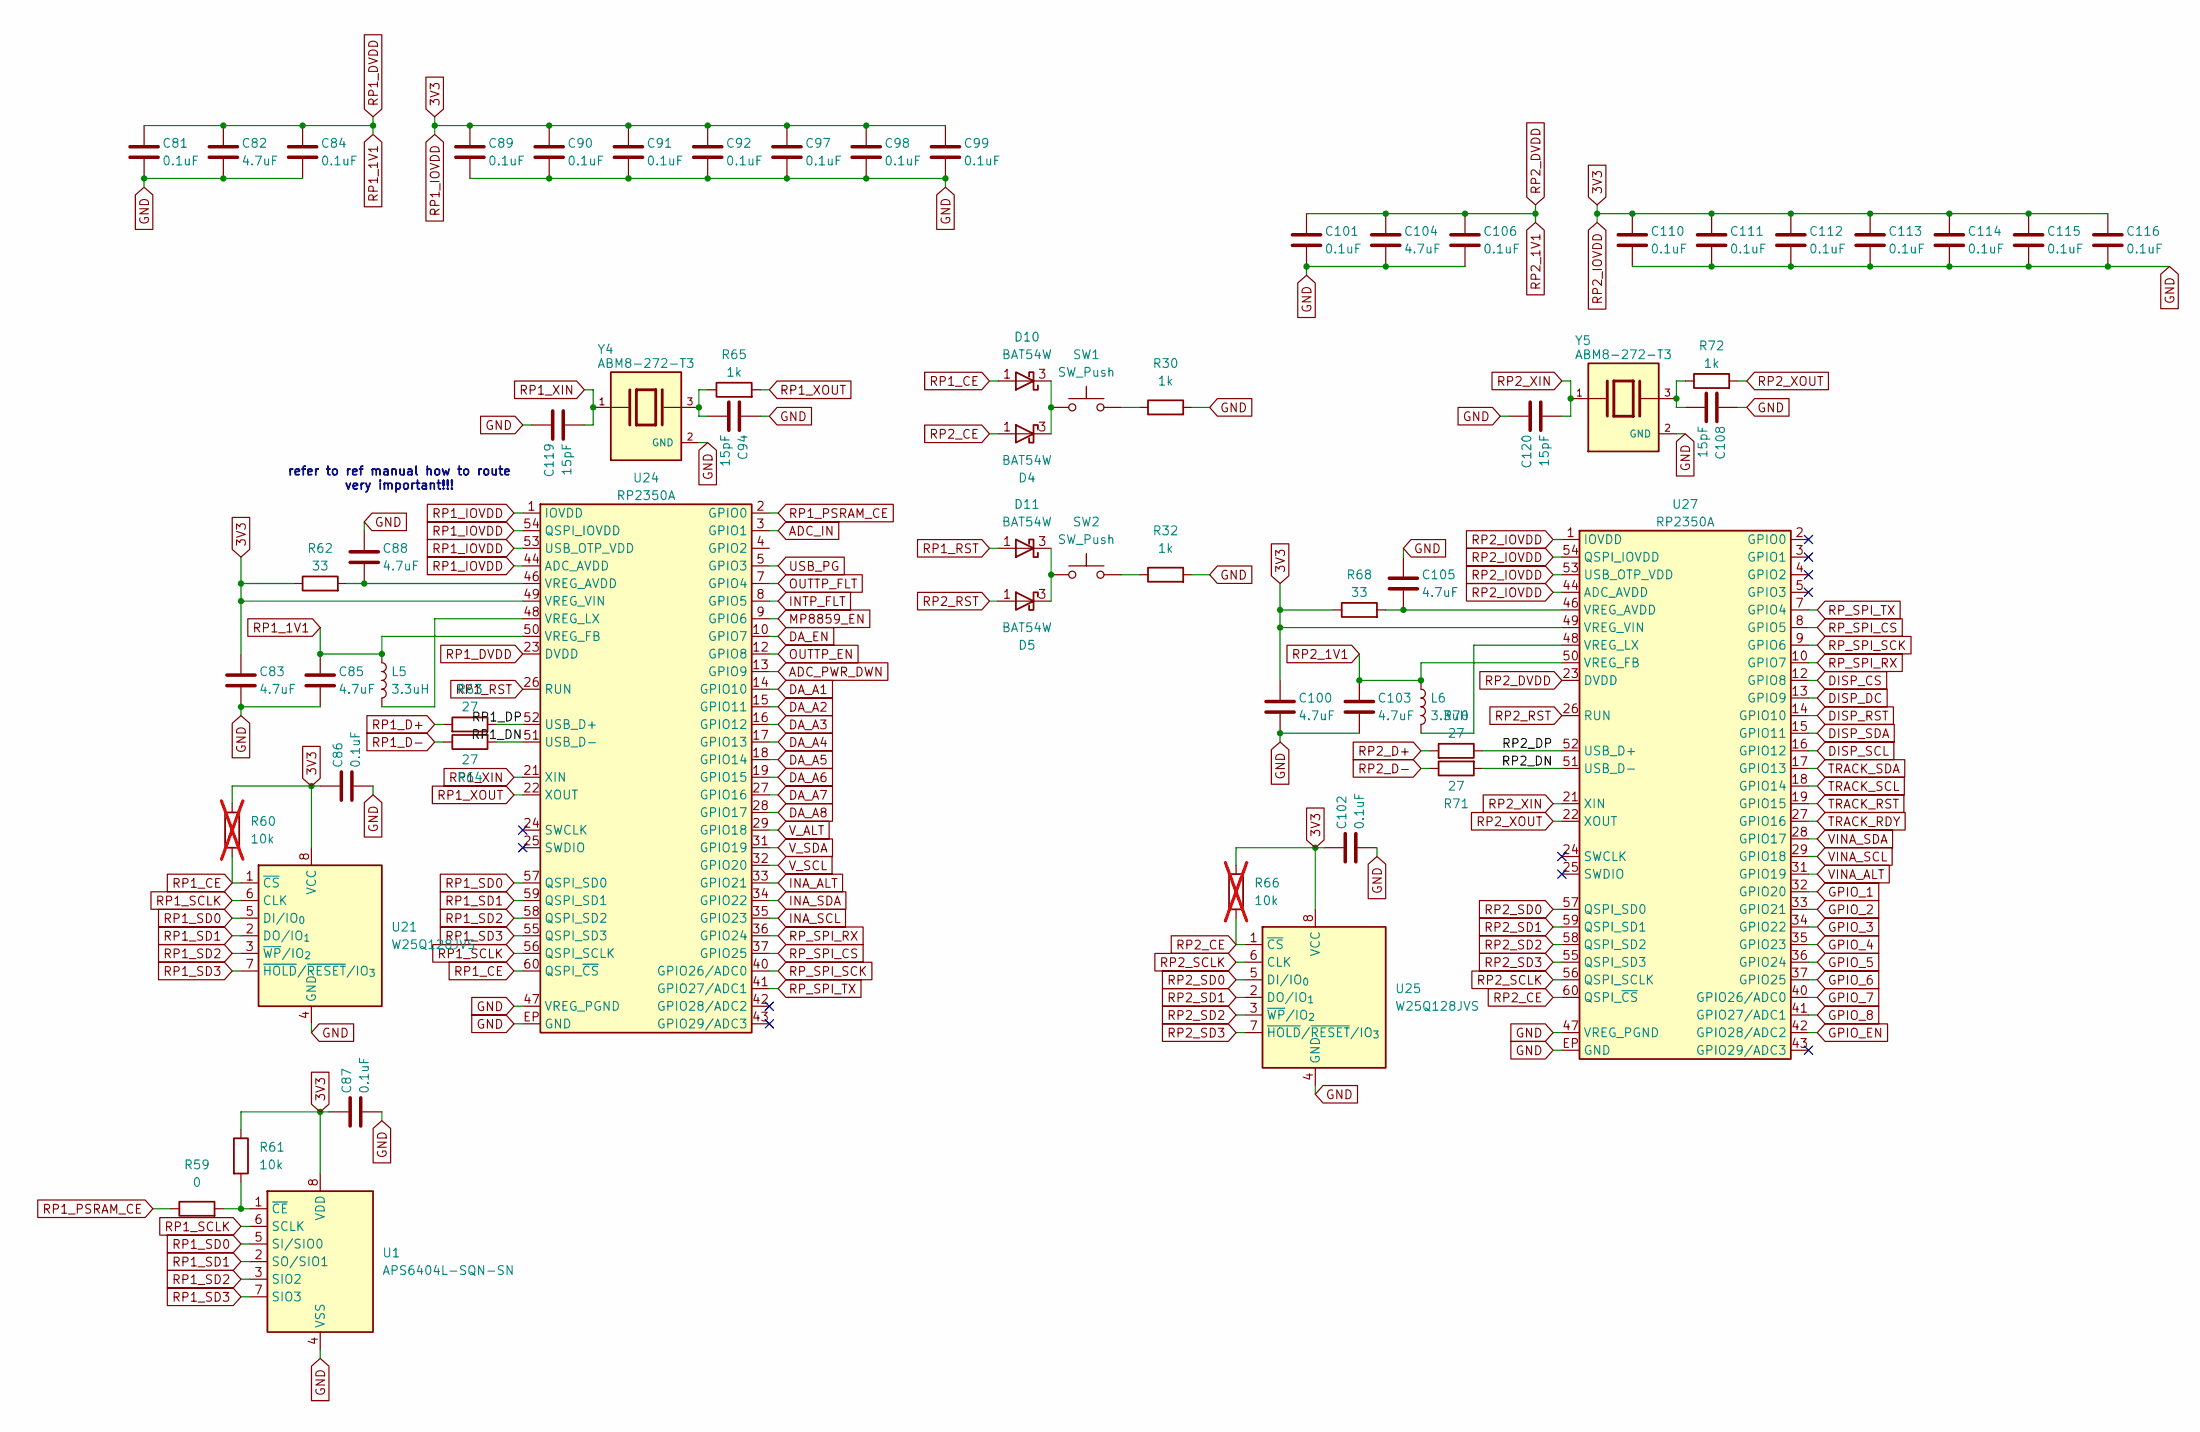
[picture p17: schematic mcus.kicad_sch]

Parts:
C81, C84, C86, C87, C89, C90, C91, C92, C97, C98, C99, C101, C102, C106, C110, C111, C112, C113, C114, C115, C116: 0.1uF; C_0402_1005Metric; MPN CL05B104KB54PNC
C82, C83, C85, C88, C100, C103, C104, C105: 4.7uF; C_0402_1005Metric; MPN CL05A475MP5NRNC
C94, C108, C119, C120: 15pF; C_0402_1005Metric; MPN 0402CG150J500NT
D4, D5, D10, D11: BAT54W; SOT-323_SC-70; MPN BAT54W
L5, L6: 3.3uH; AOTA-B201610S3R3-101-T; MPN AOTA-B201610S3R3-101-T
R30, R32, R65, R72: 1k; R_0402_1005Metric; MPN 0402WGF1001TCE
R59: 0; R_0402_1005Metric; MPN 0402WGF0000TCE
R60, R66: 10k; R_0402_1005Metric; MPN 0402WGF1002TCE; not fitted
R61: 10k; R_0402_1005Metric; MPN 0402WGF1002TCE
R62, R68: 33; R_0402_1005Metric; MPN 0402WGF330JTCE
R63, R64, R70, R71: 27; R_0603_1608Metric; MPN 0603WAF270JT5E
SW1, SW2: SW_Push; SW_TS-1088-AR02016; MPN TS-1088-AR02016
U1: APS6404L-SQN-SN; SOP-8_L4.9-W3.9-P1.27-LS6.0-BL; MPN APS6404L-SQN-SN
U21, U25: W25Q128JVS; SOIC-8_5.3x5.3mm_P1.27mm; MPN W25Q128JVSIQ
U24, U27: RP2350A; QFN-60-1EP_7x7mm_P0.4mm_EP3.4x3.4mm_ThermalVias; MPN RP2350A
Y4, Y5: ABM8-272-T3; XTAL_ABM8-272-T3; PARTREV 07-29-20

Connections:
3V3: C83.2, C86.2, C87.2, C89.2, C90.2, C91.2, C92.2, C97.2, C98.2, C99.2, C100.2, C102.2, C110.2, C111.2, C112.2, C113.2, C114.2, C115.2, C116.2, R60.1, R61.1, R62.1, R66.1, R68.1, U1.8 (VDD), U21.8 (VCC), U24.1 (IOVDD), U24.11 (IOVDD), U24.20 (IOVDD), U24.30 (IOVDD), U24.38 (IOVDD), U24.44 (ADC_AVDD), U24.45 (IOVDD), U24.49 (VREG_VIN), U24.53 (USB_OTP_VDD), U24.54 (QSPI_IOVDD), U25.8 (VCC), U27.1 (IOVDD), U27.11 (IOVDD), U27.20 (IOVDD), U27.30 (IOVDD), U27.38 (IOVDD), U27.44 (ADC_AVDD), U27.45 (IOVDD), U27.49 (VREG_VIN), U27.53 (USB_OTP_VDD), U27.54 (QSPI_IOVDD); also elsewhere on the board
/MCUs/RP1_DN: R64.2, U24.51 (USB_D-)
/MCUs/RP1_DP: R63.1, U24.52 (USB_D+)
/MCUs/RP2_DN: R71.2, U27.51 (USB_D-)
/MCUs/RP2_DP: R70.1, U27.52 (USB_D+)
ADC_IN: U24.3 (GPIO1); also elsewhere on the board
ADC_PWR_DWN: U24.13 (GPIO9)
DA_A1: U24.14 (GPIO10); also elsewhere on the board
DA_A2: U24.15 (GPIO11); also elsewhere on the board
DA_A3: U24.16 (GPIO12); also elsewhere on the board
DA_A4: U24.17 (GPIO13); also elsewhere on the board
DA_A5: U24.18 (GPIO14); also elsewhere on the board
DA_A6: U24.19 (GPIO15); also elsewhere on the board
DA_A7: U24.27 (GPIO16); also elsewhere on the board
DA_A8: U24.28 (GPIO17); also elsewhere on the board
DA_EN: U24.10 (GPIO7); also elsewhere on the board
DISP_CS: U27.12 (GPIO8); also elsewhere on the board
DISP_DC: U27.13 (GPIO9); also elsewhere on the board
DISP_RST: U27.14 (GPIO10); also elsewhere on the board
DISP_SCL: U27.16 (GPIO12); also elsewhere on the board
DISP_SDA: U27.15 (GPIO11); also elsewhere on the board
GND: C81.1, C82.1, C83.1, C84.1, C85.1, C86.1, C87.1, C88.2, C89.1, C90.1, C91.1, C92.1, C94.2, C97.1, C98.1, C99.1, C100.1, C101.1, C102.1, C103.1, C104.1, C105.2, C106.1, C108.2, C110.1, C111.1, C112.1, C113.1, C114.1, C115.1, C116.1, C119.2, C120.2, R30.2, R32.2, U1.4 (VSS), U21.4 (GND), U24.47 (VREG_PGND), U24.EP (GND), U25.4 (GND), U27.47 (VREG_PGND), U27.EP (GND), Y4.2 (GND), Y4.4 (GND), Y5.2 (GND), Y5.4 (GND); also elsewhere on the board
GPIO_1: U27.32 (GPIO20); also elsewhere on the board
GPIO_2: U27.33 (GPIO21); also elsewhere on the board
GPIO_3: U27.34 (GPIO22); also elsewhere on the board
GPIO_4: U27.35 (GPIO23); also elsewhere on the board
GPIO_5: U27.36 (GPIO24); also elsewhere on the board
GPIO_6: U27.37 (GPIO25); also elsewhere on the board
GPIO_7: U27.40 (GPIO26/ADC0); also elsewhere on the board
GPIO_8: U27.41 (GPIO27/ADC1); also elsewhere on the board
GPIO_EN: U27.42 (GPIO28/ADC2); also elsewhere on the board
INA_ALT: U24.33 (GPIO21); also elsewhere on the board
INA_SCL: U24.35 (GPIO23); also elsewhere on the board
INA_SDA: U24.34 (GPIO22); also elsewhere on the board
INTP_FLT: U24.8 (GPIO5); also elsewhere on the board
MP8859_EN: U24.9 (GPIO6); also elsewhere on the board
unnamed: C94.1, R65.1, Y4.3
unnamed: C108.1, R72.1, Y5.3
unnamed: D4.3 (K), D10.3 (K), SW1.1
unnamed: D5.3 (K), D11.3 (K), SW2.1
unnamed: R30.1, SW1.2
unnamed: R32.1, SW2.2
unnamed: R59.2, R61.2, U1.1 (~CE)
unnamed: C88.1, R62.2, U24.46 (VREG_AVDD)
unnamed: L5.2, U24.48 (VREG_LX)
unnamed: C105.1, R68.2, U27.46 (VREG_AVDD)
unnamed: L6.2, U27.48 (VREG_LX)
OUTTP_EN: U24.12 (GPIO8); also elsewhere on the board
OUTTP_FLT: U24.7 (GPIO4); also elsewhere on the board
RP1_1V1: C81.2, C82.2, C84.2, C85.2, L5.1, U24.6 (DVDD), U24.23 (DVDD), U24.39 (DVDD), U24.50 (VREG_FB)
RP1_CE: D10.1 (A), R60.2, U21.1 (~CS), U24.60 (QSPI_~CS)
RP1_D+: R63.2; also elsewhere on the board
RP1_D-: R64.1; also elsewhere on the board
RP1_PSRAM_CE: R59.1, U24.2 (GPIO0)
RP1_RST: D11.1 (A), U24.26 (RUN)
RP1_SCLK: U1.6 (SCLK), U21.6 (CLK), U24.56 (QSPI_SCLK)
RP1_SD0: U1.5 (SI/SIO0), U21.5 (DI/IO_{0}), U24.57 (QSPI_SD0)
RP1_SD1: U1.2 (SO/SIO1), U21.2 (DO/IO_{1}), U24.59 (QSPI_SD1)
RP1_SD2: U1.3 (SIO2), U21.3 (~WP/IO_{2}), U24.58 (QSPI_SD2)
RP1_SD3: U1.7 (SIO3), U21.7 (~HOLD/~RESET/IO_{3}), U24.55 (QSPI_SD3)
RP1_XIN: C119.1, U24.21 (XIN), Y4.1
RP1_XOUT: R65.2, U24.22 (XOUT)
RP2_1V1: C101.2, C103.2, C104.2, C106.2, L6.1, U27.6 (DVDD), U27.23 (DVDD), U27.39 (DVDD), U27.50 (VREG_FB)
RP2_CE: D4.1 (A), R66.2, U25.1 (~CS), U27.60 (QSPI_~CS)
RP2_D+: R70.2; also elsewhere on the board
RP2_D-: R71.1; also elsewhere on the board
RP2_RST: D5.1 (A), U27.26 (RUN)
RP2_SCLK: U25.6 (CLK), U27.56 (QSPI_SCLK)
RP2_SD0: U25.5 (DI/IO_{0}), U27.57 (QSPI_SD0)
RP2_SD1: U25.2 (DO/IO_{1}), U27.59 (QSPI_SD1)
RP2_SD2: U25.3 (~WP/IO_{2}), U27.58 (QSPI_SD2)
RP2_SD3: U25.7 (~HOLD/~RESET/IO_{3}), U27.55 (QSPI_SD3)
RP2_XIN: C120.1, U27.21 (XIN), Y5.1
RP2_XOUT: R72.2, U27.22 (XOUT)
RP_SPI_CS: U24.37 (GPIO25), U27.8 (GPIO5)
RP_SPI_RX: U24.36 (GPIO24), U27.10 (GPIO7)
RP_SPI_SCK: U24.40 (GPIO26/ADC0), U27.9 (GPIO6)
RP_SPI_TX: U24.41 (GPIO27/ADC1), U27.7 (GPIO4)
TRACK_RDY: U27.27 (GPIO16); also elsewhere on the board
TRACK_RST: U27.19 (GPIO15); also elsewhere on the board
TRACK_SCL: U27.18 (GPIO14); also elsewhere on the board
TRACK_SDA: U27.17 (GPIO13); also elsewhere on the board
USB_PG: U24.5 (GPIO3); also elsewhere on the board
VINA_ALT: U27.31 (GPIO19); also elsewhere on the board
VINA_SCL: U27.29 (GPIO18); also elsewhere on the board
VINA_SDA: U27.28 (GPIO17); also elsewhere on the board
V_ALT: U24.29 (GPIO18); also elsewhere on the board
V_SCL: U24.32 (GPIO20); also elsewhere on the board
V_SDA: U24.31 (GPIO19); also elsewhere on the board

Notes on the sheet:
refer to ref manual how to route very important!!!

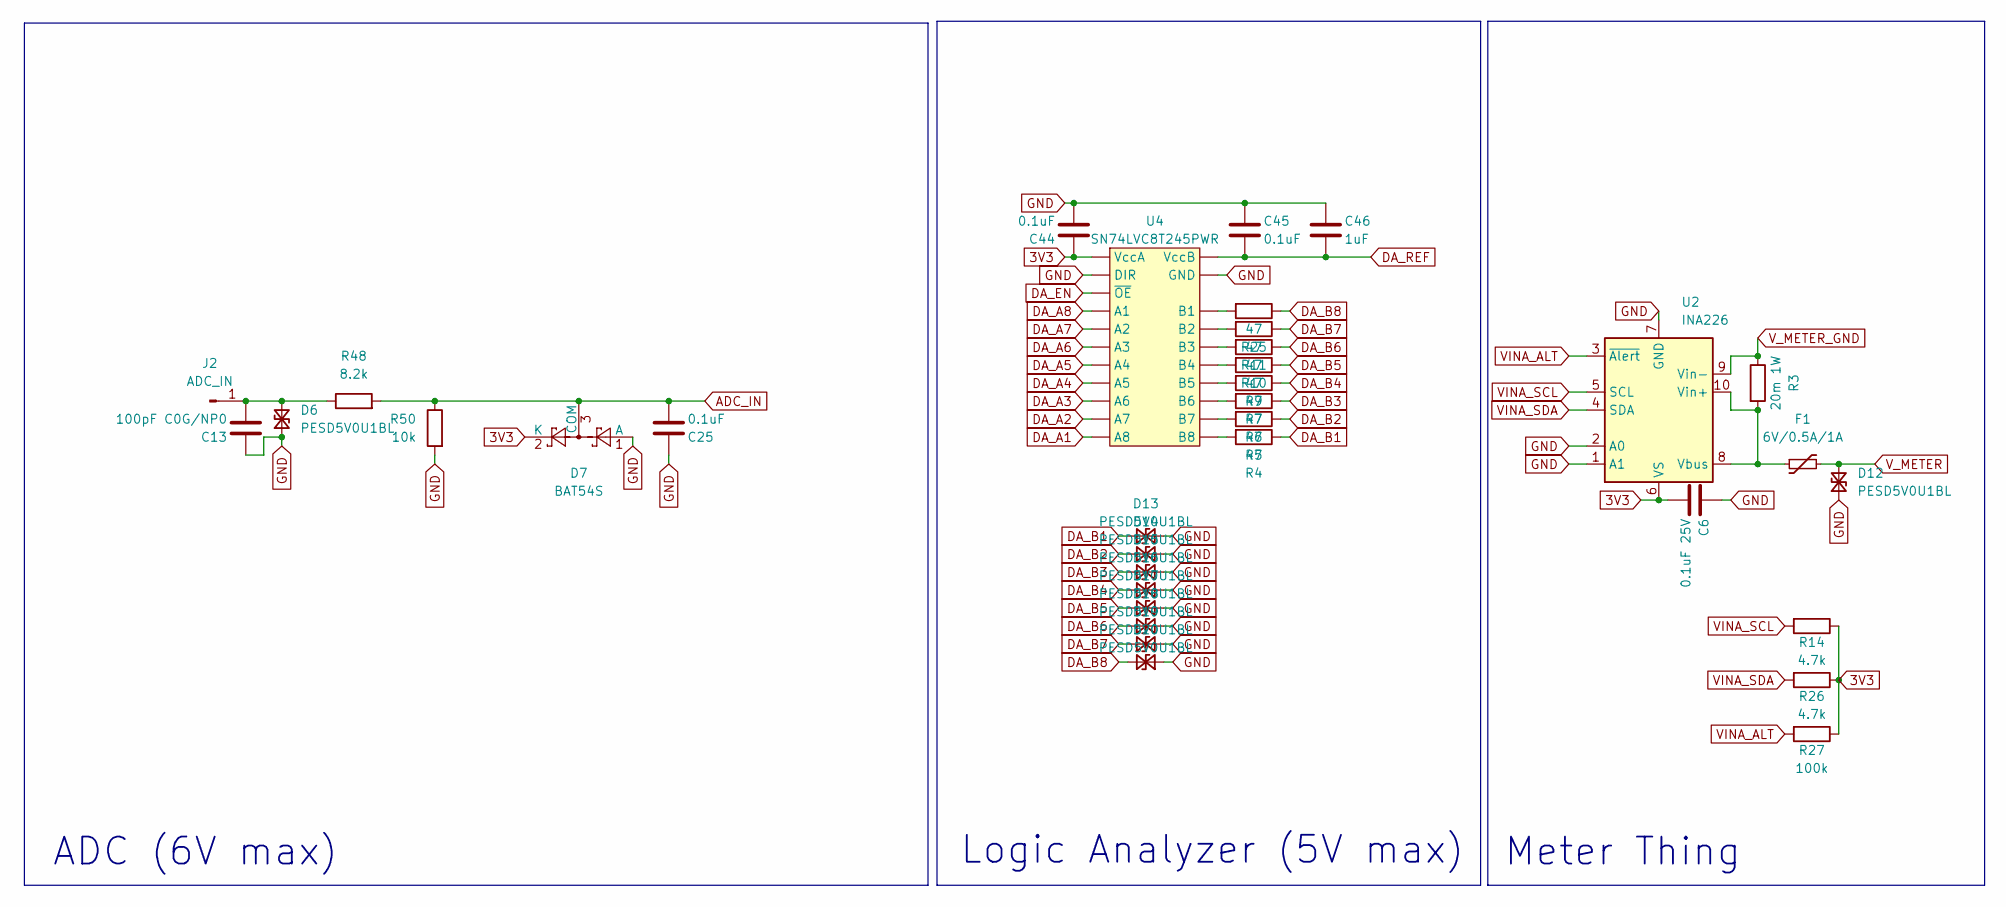
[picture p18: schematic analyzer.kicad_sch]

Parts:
C6: 0.1uF 25V; C_0402_1005Metric; MPN CL05B104KB54PNC
C13: 100pF C0G/NP0; C_0402_1005Metric; MPN 0402CG101J500NT
C25, C44, C45: 0.1uF; C_0402_1005Metric; MPN CL05B104KB54PNC
C46: 1uF; C_0402_1005Metric; MPN CL05A105KA5NQNC
D6, D12, D13, D14, D15, D16, D17, D18, D19, D20: PESD5V0U1BL; D_SOD-882; MPN PESD5V0U1BL
D7: BAT54S; SOT-23; MPN BAT54S
F1: 6V/0.5A/1A; 1206; MPN 1206L050YR
J2: ADC_IN; PinHeader_1x01_P2.54mm_Vertical
R3: 20m 1W; R_1206_3216Metric; MPN RLS12FTCR020
R4, R5, R6, R7, R9, R10, R11, R25: 47; R_0402_1005Metric; MPN 0402WGF470JTCE
R14, R26: 4.7k; R_0402_1005Metric; MPN 0402WGF4701TCE
R27: 100k; R_0402_1005Metric; MPN 0402WGF1003TCE
R48: 8.2k; R_0402_1005Metric; MPN 0402WGF8201TCE
R50: 10k; R_0402_1005Metric; MPN 0402WGF1002TCE
U2: INA226; TSSOP-10_3x3mm_P0.5mm; MPN INA226AIDGSR
U4: SN74LVC8T245PWR; SOP65P640X120-24N; MPN SN74LVC8T245PWR; LCSC C27643

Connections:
3V3: C6.1, C44.2, D7.2 (K), R14.1, R26.1, R27.1, U2.6 (VS), U4.1 (VccA); also elsewhere on the board
ADC_IN: C25.1, D7.3 (COM), R48.2, R50.1; also elsewhere on the board
DA_A1: U4.10 (A8); also elsewhere on the board
DA_A2: U4.9 (A7); also elsewhere on the board
DA_A3: U4.8 (A6); also elsewhere on the board
DA_A4: U4.7 (A5); also elsewhere on the board
DA_A5: U4.6 (A4); also elsewhere on the board
DA_A6: U4.5 (A3); also elsewhere on the board
DA_A7: U4.4 (A2); also elsewhere on the board
DA_A8: U4.3 (A1); also elsewhere on the board
DA_B1: D13.2 (A2), R4.1; also elsewhere on the board
DA_B2: D14.2 (A2), R5.1; also elsewhere on the board
DA_B3: D15.2 (A2), R6.1; also elsewhere on the board
DA_B4: D16.2 (A2), R7.1; also elsewhere on the board
DA_B5: D17.2 (A2), R9.1; also elsewhere on the board
DA_B6: D18.2 (A2), R10.1; also elsewhere on the board
DA_B7: D19.2 (A2), R11.1; also elsewhere on the board
DA_B8: D20.2 (A2), R25.1; also elsewhere on the board
DA_EN: U4.22 (~OE); also elsewhere on the board
DA_REF: C45.1, C46.1, U4.23 (VccB), U4.24 (VccB); also elsewhere on the board
GND: C6.2, C13.2, C25.2, C44.1, C45.2, C46.2, D6.1 (A1), D7.1 (A), D12.1 (A1), D13.1 (A1), D14.1 (A1), D15.1 (A1), D16.1 (A1), D17.1 (A1), D18.1 (A1), D19.1 (A1), D20.1 (A1), R50.2, U2.1 (A1), U2.2 (A0), U2.7 (GND), U4.2 (DIR), U4.11 (GND), U4.12 (GND), U4.13 (GND); also elsewhere on the board
unnamed: C13.1, D6.2 (A2), J2.1 (Pin_1_1), R48.1
unnamed: F1.1, R3.2, U2.8 (Vbus), U2.10 (Vin+)
unnamed: R25.2, U4.21 (B1)
unnamed: R11.2, U4.20 (B2)
unnamed: R10.2, U4.19 (B3)
unnamed: R9.2, U4.18 (B4)
unnamed: R7.2, U4.17 (B5)
unnamed: R6.2, U4.16 (B6)
unnamed: R5.2, U4.15 (B7)
unnamed: R4.2, U4.14 (B8)
VINA_ALT: R27.2, U2.3 (~Alert); also elsewhere on the board
VINA_SCL: R14.2, U2.5 (SCL); also elsewhere on the board
VINA_SDA: R26.2, U2.4 (SDA); also elsewhere on the board
V_METER: D12.2 (A2), F1.2; also elsewhere on the board
V_METER_GND: R3.1, U2.9 (Vin-); also elsewhere on the board

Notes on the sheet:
Logic Analyzer (5V max)
ADC (6V max)
Meter Thing

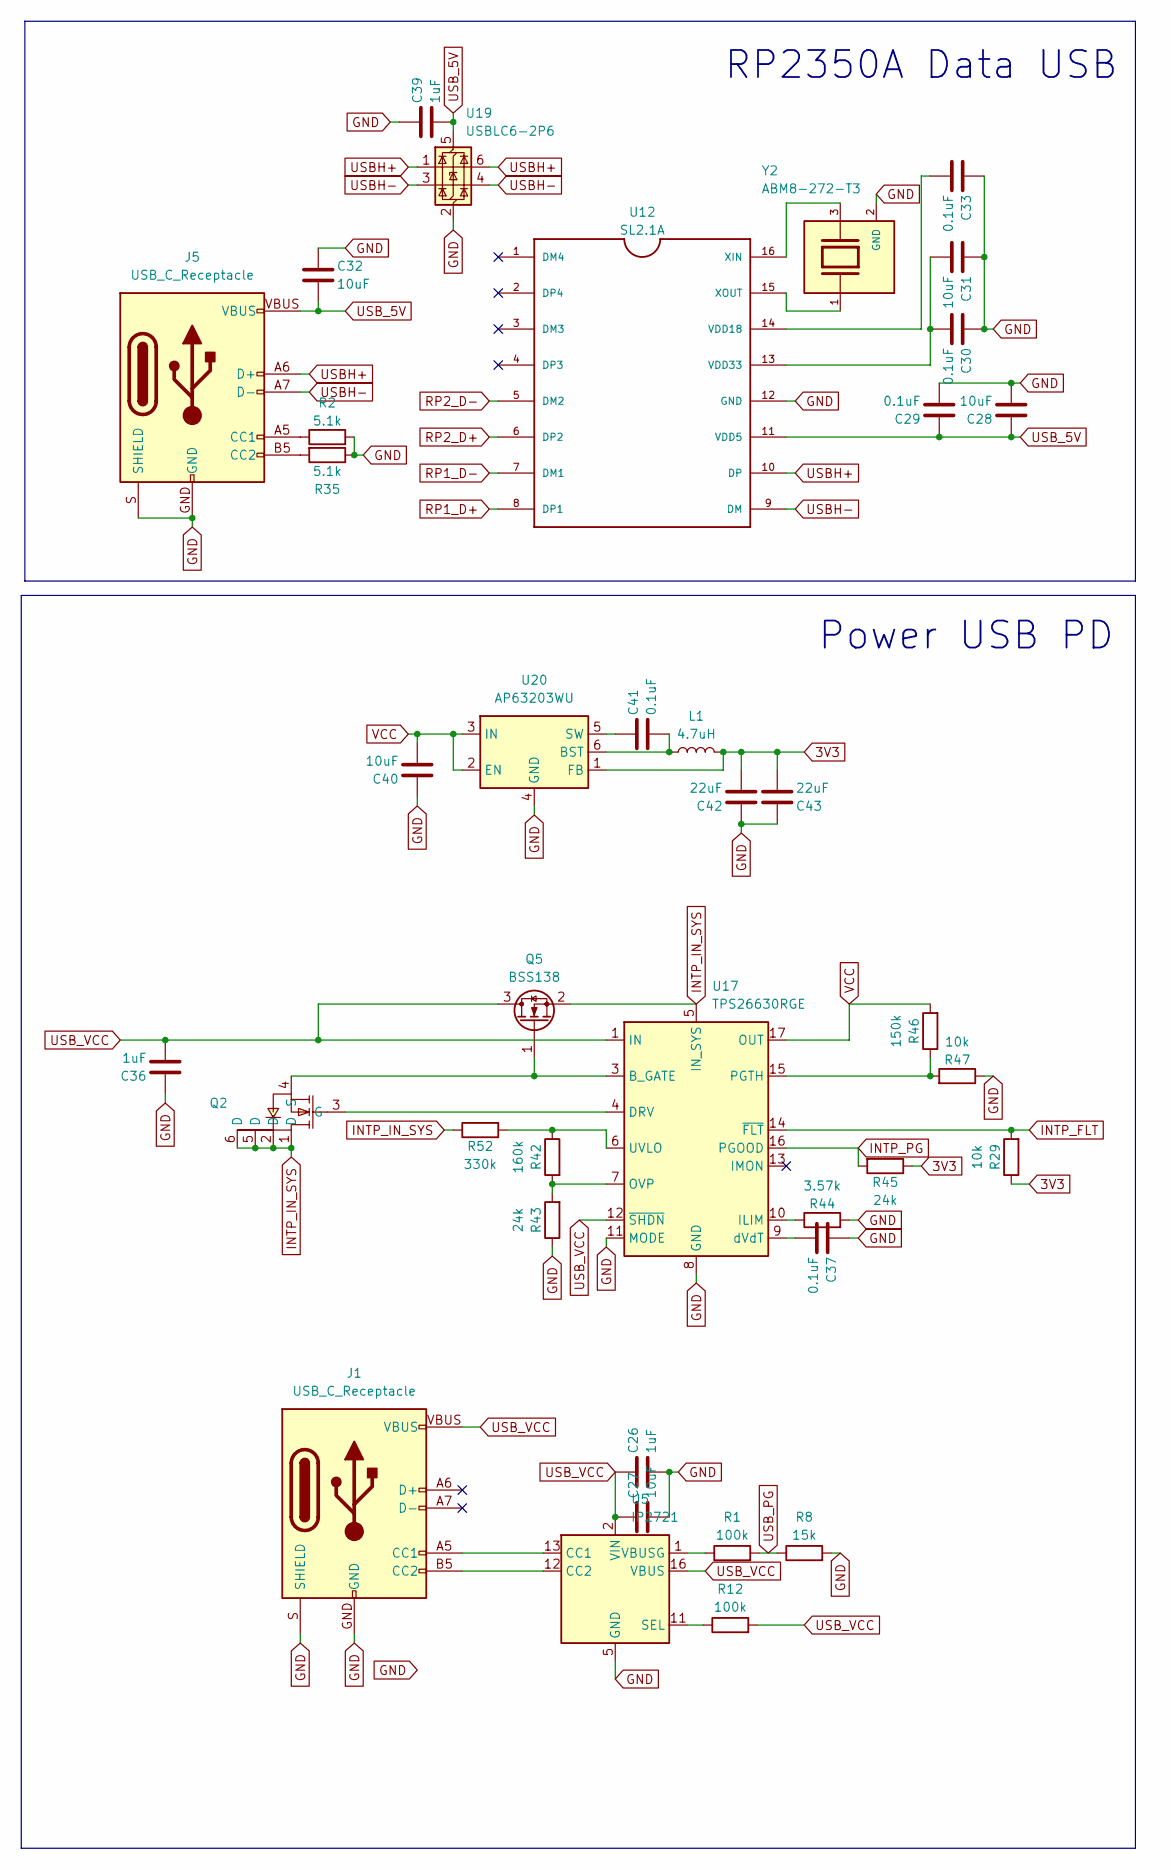
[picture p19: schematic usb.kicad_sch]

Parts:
C26, C36, C39: 1uF; C_0402_1005Metric; MPN CL05A105KA5NQNC
C27, C28, C31, C32, C40: 10uF; C_0805_2012Metric; MPN CL21A106KAYNNNE
C29, C30, C33, C37, C41: 0.1uF; C_0402_1005Metric; MPN CL05B104KB54PNC
C42, C43: 22uF; C_0805_2012Metric; MPN CL21A226MAQNNNE
J1, J5: USB_C_Receptacle; USB-C_16; MPN TYPE-C-31-M-12
L1: 4.7uH; L_TechFuse_SL0420; MPN SRP4020TA-4R7M
Q2: STT6N3LLH6_C3021100; SOT-23-6_L2.9-W1.6-P0.95-LS2.8-BR; MPN STT6N3LLH6; LCSC Part C3021100
Q5: BSS138; SOT-23; MPN BSS138
R1, R12: 100k; R_0402_1005Metric; MPN 0402WGF1003TCE
R2, R35: 5.1k; R_0402_1005Metric; MPN 0402WGF5101TCE
R8: 15k; R_0402_1005Metric; MPN 0402WGF1502TCE
R29, R47: 10k; R_0402_1005Metric; MPN 0402WGF1002TCE
R42: 160k; R_0603_1608Metric; MPN 0603WAF1603T5E
R43, R45: 24k; R_0402_1005Metric; MPN 0402WGF2402TCE
R44: 3.57k; R_0603_1608Metric; MPN 0603WAF3601T5E
R46: 150k; R_0402_1005Metric; MPN 0402WGF1503TCE
R52: 330k; R_0402_1005Metric; MPN 0402WGF3303TCE
U5: IP2721; TSSOP-16_4.4x5mm_P0.65mm; MPN IP2721
U12: SL2.1A; SO16; MPN SL2.1A
U17: TPS26630RGE; Texas_RGE0024H_VQFN-24-1EP_4x4mm_P0.5mm_EP2.7x2.7mm_Thermal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; MPN TPS26630RGER
U19: USBLC6-2P6; SOT-666; MPN USBLC6-2P6
U20: AP63203WU; TSOT-23-6; MPN AP63203WU-7
Y2: ABM8-272-T3; XTAL_ABM8-272-T3; PARTREV 07-29-20

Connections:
3V3: C42.1, C43.1, L1.2, R29.1, R45.1, U20.1 (FB); also elsewhere on the board
GND: C26.1, C27.1, C28.1, C29.1, C30.2, C31.2, C32.2, C33.2, C36.2, C37.2, C39.2, C40.2, C42.2, C43.2, J1.GND, J1.S (SHIELD), J5.GND, J5.S (SHIELD), R2.2, R8.2, R35.1, R43.1, R44.2, R47.1, U5.5 (GND), U12.12 (GND), U17.8 (GND), U17.11 (MODE), U17.25 (GND), U19.2 (GND), U20.4 (GND), Y2.2 (GND), Y2.4 (GND); also elsewhere on the board
INTP_FLT: R29.2, U17.14 (~FLT); also elsewhere on the board
INTP_IN_SYS: Q2.1 (D), Q2.2 (D), Q2.5 (D), Q2.6 (D), Q5.2 (S), R52.1, U17.5 (IN_SYS)
INTP_PG: R45.2, U17.16 (PGOOD)
unnamed: J1.A5 (CC1), U5.13 (CC1)
unnamed: J1.B5 (CC2), U5.12 (CC2)
unnamed: J5.A5 (CC1), R2.1
unnamed: J5.B5 (CC2), R35.2
unnamed: Q2.3 (G), U17.4 (DRV)
unnamed: Q2.4 (S), Q5.1 (G), U17.3 (B_GATE)
unnamed: R12.1, U5.11 (SEL)
unnamed: R1.1, U5.1 (VBUSG)
unnamed: C33.1, U12.14 (VDD18)
unnamed: C30.1, C31.1, U12.13 (VDD33)
unnamed: U12.16 (XIN), Y2.3
unnamed: U12.15 (XOUT), Y2.1
unnamed: R44.1, U17.10 (ILIM)
unnamed: R42.2, R43.2, U17.7 (OVP)
unnamed: R46.1, R47.2, U17.15 (PGTH)
unnamed: R42.1, R52.2, U17.6 (UVLO)
unnamed: C37.1, U17.9 (dVdT)
unnamed: C41.1, L1.1, U20.6 (BST)
unnamed: C41.2, U20.5 (SW)
RP1_D+: U12.8 (DP1); also elsewhere on the board
RP1_D-: U12.7 (DM1); also elsewhere on the board
RP2_D+: U12.6 (DP2); also elsewhere on the board
RP2_D-: U12.5 (DM2); also elsewhere on the board
USBH+: J5.A6 (D+), J5.B6 (D+), U12.10 (DP), U19.1 (I/O1), U19.6 (I/O1)
USBH-: J5.A7 (D-), J5.B7 (D-), U12.9 (DM), U19.3 (I/O2), U19.4 (I/O2)
USB_5V: C28.2, C29.2, C32.1, C39.1, J5.VBUS, U12.11 (VDD5), U19.5 (VBUS)
USB_PG: R1.2, R8.1; also elsewhere on the board
USB_VCC: C26.2, C27.2, C36.1, J1.VBUS, Q5.3 (D), R12.2, U5.2 (VIN), U5.16 (VBUS), U17.1 (IN), U17.2 (IN), U17.12 (~SHDN)
VCC: C40.1, R46.2, U17.17 (OUT), U17.18 (OUT), U20.2 (EN), U20.3 (IN); also elsewhere on the board

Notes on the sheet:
Power USB PD
RP2350A Data USB

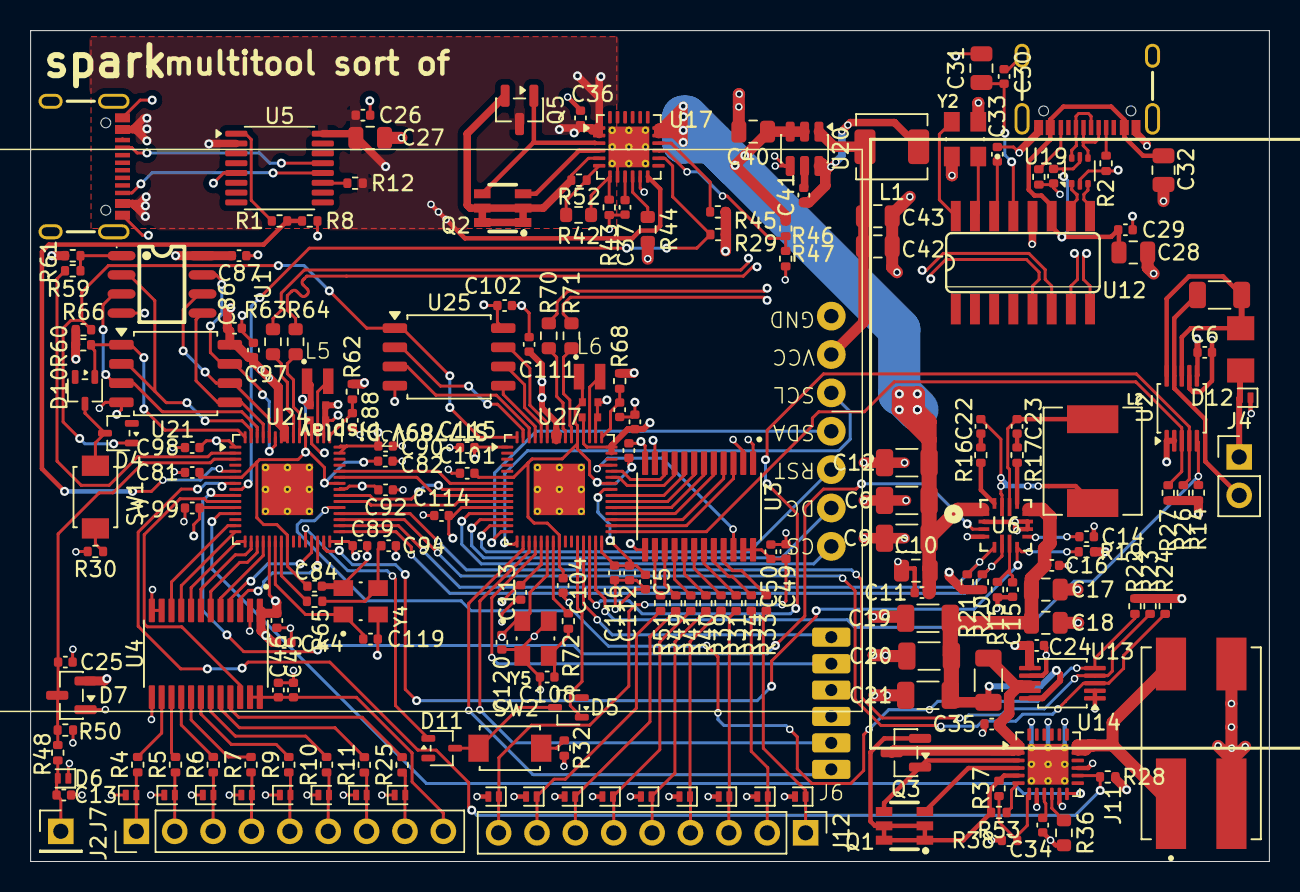
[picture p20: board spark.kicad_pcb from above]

Board: 4 copper layers, 82.0 x 55.0 mm, 202 parts (0 on the bottom side), 170 nets.

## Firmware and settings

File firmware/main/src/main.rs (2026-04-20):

#![no_std]
#![no_main]

use defmt::*;
use defmt_rtt as _;
use embedded_hal::delay::DelayNs;
use embedded_hal::digital::OutputPin;
#[cfg(target_arch = "riscv32")]
use panic_halt as _;
#[cfg(target_arch = "arm")]
use panic_probe as _;

// Alias for our HAL crate
use hal::entry;
use hal::fugit::RateExtU32;
use embedded_hal::spi::SpiBus;
use hal::clocks::Clock;


#[cfg(rp2350)]
use rp235x_hal as hal;

#[cfg(rp2040)]
use rp2040_hal as hal;

// use bsp::entry;
// use bsp::hal;
// use rp_pico as bsp;

/// The linker will place this boot block at the start of our program image. We
/// need this to help the ROM bootloader get our code up and running.
/// Note: This boot block is not necessary when using a rp-hal based BSP
/// as the BSPs already perform this step.
#[unsafe(link_section = ".boot2")]
#[used]
#[cfg(rp2040)]
pub static BOOT2: [u8; 256] = rp2040_boot2::BOOT_LOADER_W25Q080;

/// Tell the Boot ROM about our application
#[unsafe(link_section = ".start_block")]
#[used]
#[cfg(rp2350)]
pub static IMAGE_DEF: hal::block::ImageDef = hal::block::ImageDef::secure_exe();

/// External high-speed crystal on the Raspberry Pi Pico 2 board is 12 MHz.
/// Adjust if your board has a different frequency
const XTAL_FREQ_HZ: u32 = 12_000_000u32;

/// Entry point to our bare-metal application.
///
/// The `#[hal::entry]` macro ensures the Cortex-M start-up code calls this function
/// as soon as all global variables and the spinlock are initialised.
///
/// The function configures the rp2040 and rp235x peripherals, then toggles a GPIO pin in
/// an infinite loop. If there is an LED connected to that pin, it will blink.
#[entry]
fn main() -> ! {
    info!("Program start");
    // Grab our singleton objects
    let mut pac = hal::pac::Peripherals::take().unwrap();

    // Set up the watchdog driver - needed by the clock setup code
    let mut watchdog = hal::Watchdog::new(pac.WATCHDOG);

    // Configure the clocks
    let clocks = hal::clocks::init_clocks_and_plls(
        XTAL_FREQ_HZ,
        pac.XOSC,
        pac.CLOCKS,
        pac.PLL_SYS,
        pac.PLL_USB,
        &mut pac.RESETS,
        &mut watchdog,
    )
    .unwrap();

    #[cfg(rp2040)]
    let mut timer = hal::Timer::new(pac.TIMER, &mut pac.RESETS, &clocks);

    #[cfg(rp2350)]
    let mut timer = hal::Timer::new_timer0(pac.TIMER0, &mut pac.RESETS, &clocks);

    // The single-cycle I/O block controls our GPIO pins
    let sio = hal::Sio::new(pac.SIO);

    // Set the pins to their default state
    let pins = hal::gpio::Pins::new(
        pac.IO_BANK0,
        pac.PADS_BANK0,
        sio.gpio_bank0,
        &mut pac.RESETS,
    );

    // SPI Slave Configuration
    // SPI1: RX=24, CS=25, SCK=26, TX=27
    let spi = hal::Spi::<_, _, _, 8>::new(pac.SPI1, (
        pins.gpio27.into_function::<hal::gpio::FunctionSpi>(), // TX
        pins.gpio24.into_function::<hal::gpio::FunctionSpi>(), // RX
        pins.gpio26.into_function::<hal::gpio::FunctionSpi>(), // SCK
    ));

    let mut spi = spi.init(
        &mut pac.RESETS,
        clocks.peripheral_clock.freq(),
        1_000_000_u32.Hz(), // 1 MHz - matches master
        &embedded_hal::spi::Mode {
            polarity: embedded_hal::spi::Polarity::IdleHigh,
            phase: embedded_hal::spi::Phase::CaptureOnSecondTransition,
        },
    );

    let _cs_pin = pins.gpio25.into_floating_input();

    // Initialize GPIO pins 10-17 as logic analyzer inputs
    let _g10 = pins.gpio10.into_floating_input();
    let _g11 = pins.gpio11.into_floating_input();
    let _g12 = pins.gpio12.into_floating_input();
    let _g13 = pins.gpio13.into_floating_input();
    let _g14 = pins.gpio14.into_floating_input();
    let _g15 = pins.gpio15.into_floating_input();
    let _g16 = pins.gpio16.into_floating_input();
    let _g17 = pins.gpio17.into_floating_input();

    let mut capture_buffer = [0u8; 1000];

    loop {
        let mut cmd_buf = [0u8; 1];
        let mut response_buf = [0u8; 1];

        // Read SPI command
        if let Ok(_) = spi.read(&mut cmd_buf) {
            let cmd = cmd_buf[0];
            
            // CMD = 0x01 (Start Capture)
            if cmd == 0x01 {
                // Actually read GPIO as fast as possible in a tight CPU loop
                // Pins 10-17 are correctly aligned if we shift by 10 maybe
                for _i in 0..100 {
                    // Loop unrolling for maximum CPU capture speed
                    capture_buffer[0] = (unsafe { (*hal::pac::SIO::PTR).gpio_in() }.read().bits() >> 10) as u8;
                    capture_buffer[1] = (unsafe { (*hal::pac::SIO::PTR).gpio_in() }.read().bits() >> 10) as u8;
                    capture_buffer[2] = (unsafe { (*hal::pac::SIO::PTR).gpio_in() }.read().bits() >> 10) as u8;
                    capture_buffer[3] = (unsafe { (*hal::pac::SIO::PTR).gpio_in() }.read().bits() >> 10) as u8;
                    capture_buffer[4] = (unsafe { (*hal::pac::SIO::PTR).gpio_in() }.read().bits() >> 10) as u8;
                    capture_buffer[5] = (unsafe { (*hal::pac::SIO::PTR).gpio_in() }.read().bits() >> 10) as u8;
                    capture_buffer[6] = (unsafe { (*hal::pac::SIO::PTR).gpio_in() }.read().bits() >> 10) as u8;
                    capture_buffer[7] = (unsafe { (*hal::pac::SIO::PTR).gpio_in() }.read().bits() >> 10) as u8;
                    capture_buffer[8] = (unsafe { (*hal::pac::SIO::PTR).gpio_in() }.read().bits() >> 10) as u8;
                    capture_buffer[9] = (unsafe { (*hal::pac::SIO::PTR).gpio_in() }.read().bits() >> 10) as u8;
                }
                
                // return length or something
                response_buf[0] = (capture_buffer.len() & 0xFF) as u8;
                let _ = spi.write(&response_buf);
            }
        }
    }
}

/// Program metadata for `picotool info`
#[unsafe(link_section = ".bi_entries")]
#[used]
pub static PICOTOOL_ENTRIES: [hal::binary_info::EntryAddr; 5] = [
    hal::binary_info::rp_cargo_bin_name!(),
    hal::binary_info::rp_cargo_version!(),
    hal::binary_info::rp_program_description!(c"Blinky Example"),
    hal::binary_info::rp_cargo_homepage_url!(),
    hal::binary_info::rp_program_build_attribute!(),
];

// End of file

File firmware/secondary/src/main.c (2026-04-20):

#include <stdio.h>
#include "pico/stdlib.h"
#include "hardware/timer.h"
#include "lvgl.h"
#include "display.h"

// Global UI elements
static lv_obj_t * capture_count_label = NULL;

// Capture button callback
static void capture_btn_event_cb(lv_event_t * e) {
    lv_event_code_t code = lv_event_get_code(e);
    
    if(code == LV_EVENT_CLICKED) {
        printf("Capture button clicked!\n");
        
        // Send capture command to main MCU via SPI
        uint8_t response = spi_master_transceive(0x01); // CMD_CAPTURE = 0x01
        
        // Update the label with the response
        if (capture_count_label != NULL) {
            char buffer[32];
            snprintf(buffer, sizeof(buffer), "Count: %u", response);
            lv_label_set_text(capture_count_label, buffer);
            printf("Received capture count: %u\n", response);
        }
    }
}

// Power supply callback
static void btn_event_cb(lv_event_t * e) {
    lv_event_code_t code = lv_event_get_code(e);
    lv_obj_t * btn = lv_event_get_current_target(e);
    lv_obj_t * label = lv_obj_get_child(btn, 0);

    if(code == LV_EVENT_VALUE_CHANGED) {
        if(lv_obj_has_state(btn, LV_STATE_CHECKED)) {
            lv_label_set_text(label, "PSU: ON");
            // Add hardware logic to enable PSU here
            printf("Power Supply Enabled\n");
        }
        else {
            lv_label_set_text(label, "PSU: OFF");
            // Add hardware logic to disable PSU here
            printf("Power Supply Disabled\n");
        }
    }
}

void create_gui(void) {
    // Top-level display configurations
    static lv_style_t main_style;
    lv_style_init(&main_style);
    lv_style_set_bg_color(&main_style, lv_color_hex(0x000000));
    lv_style_set_text_color(&main_style, lv_color_hex(0xFFFFFF));
    
    lv_obj_add_style(lv_screen_active(), &main_style, 0);

    // Spark Title
    lv_obj_t * label = lv_label_create(lv_screen_active());
    lv_label_set_text(label, "Spark");
    lv_obj_set_style_text_font(label, &lv_font_montserrat_14, 0); // Need to enable font in lv_conf.h!
    lv_obj_align(label, LV_ALIGN_TOP_MID, 0, 5);

    // Power Toggle Button
    lv_obj_t * btn = lv_btn_create(lv_screen_active());
    lv_obj_add_flag(btn, LV_OBJ_FLAG_CHECKABLE);
    lv_obj_set_size(btn, 100, 40);
    lv_obj_align(btn, LV_ALIGN_TOP_MID, 0, 25);
    lv_obj_add_event_cb(btn, btn_event_cb, LV_EVENT_ALL, NULL);

    lv_obj_t * btn_label = lv_label_create(btn);
    lv_label_set_text(btn_label, "PSU: OFF");
    lv_obj_center(btn_label);

    // Capture Button
    lv_obj_t * capture_btn = lv_btn_create(lv_screen_active());
    lv_obj_set_size(capture_btn, 120, 40);
    lv_obj_align(capture_btn, LV_ALIGN_CENTER, 0, 5);
    lv_obj_add_event_cb(capture_btn, capture_btn_event_cb, LV_EVENT_CLICKED, NULL);

    lv_obj_t * capture_btn_label = lv_label_create(capture_btn);
    lv_label_set_text(capture_btn_label, "Capture");
    lv_obj_center(capture_btn_label);

    // Capture Count Label
    capture_count_label = lv_label_create(lv_screen_active());
    lv_label_set_text(capture_count_label, "Count: --");
    lv_obj_align(capture_count_label, LV_ALIGN_CENTER, 0, 50);
}

int main()
{
    stdio_init_all();
    sleep_ms(2000);

    // Initialize LVGL core
    lv_init();

    // Initialize SPI, ST7735 and LVGL display driver
    display_init();

    // Create the UI with elements
    create_gui();

    // Main event loop
    uint32_t last_tick = to_ms_since_boot(get_absolute_time());

    while (true) {
        uint32_t current_tick = to_ms_since_boot(get_absolute_time());
        uint32_t diff = current_tick - last_tick;
        lv_tick_inc(diff);
        last_tick = current_tick;

        lv_timer_handler();
        sleep_ms(5);
    }
}

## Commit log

2026-04-18 init repo
    [analyzer.kicad_sch, mcus.kicad_sch, power.kicad_sch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]
2026-04-18 Fix MPN number, adjust footprint, production files
    [bom.csv, designators.csv, mcus.kicad_sch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]
2026-04-20 Add case and case renders
2026-04-20 Add BOM and screenshots and cleanup. Updated PCB for fixed footprint for capacitor.
    [BOM.csv, bom.csv, positions.csv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]
